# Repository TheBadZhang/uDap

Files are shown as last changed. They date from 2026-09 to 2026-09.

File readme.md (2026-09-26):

# uDap2

基于 **CH32X035F8U** 的 **CMSIS-DAP 调试器 + USB↔串口桥**，单颗 USB 全速设备口同时提供
SWD 调试和一路虚拟串口。仓库包含固件（`firmware/`）、KiCad 硬件设计（`hardware/`）与上位机
脚本（`software/`）。

- 调试器：CMSIS-DAP（bulk，WinUSB）——OpenOCD / pyOCD / probe-rs 可直接使用
- 桥接串口：CDC ACM，对端是目标板上的 USART4（PB0=TX / PB1=RX），**不限制波特率**
- SWD 时钟：请求 **≥6 MHz** 自动切到「快路径」，实测读写 **125 / 121 KiB/s**（16 KiB 块）
- SWD 推荐档位：**6 MHz**（更快与更快实际同速，填高只减时序余量）
- 串口环回：**2 Mbaud 持续满载零丢字节**（96~98 % 利用率）；分块发送时 6 Mbaud 也字节无误
- 桥接吞吐天花板：约 **200 KiB/s**（≈2 Mbaud），受 USB IN 侧调度限制，与 USB 带宽无关

---

## 1. 这是什么

一块 RISC-V MCU 做成的「调试器小板」：插上 USB 后主机看到**一个 CMSIS-DAP 探针**和
**一个串口**，两者共用同一颗芯片、同一根 USB 线。它替代的是「J-Link/DAPLink + 独立 USB-TTL」
两件套，用于嵌入式目标板的调试与串口日志。

数据通路：

```mermaid
flowchart LR
    PC["主机<br/>OpenOCD / pyOCD / 串口终端"]
    subgraph DAP["uDap2 (CH32X035F8U)"]
        USBFS["USB 全速设备"]
        DAPC["CMSIS-DAP<br/>DAP.c + sw_dp.c"]
        BR["CDC ↔ USART4 桥<br/>drv_uart.c"]
    end
    TGT["目标板<br/>SWCLK / SWDIO / nRESET"]
    UART["目标板 USART<br/>PB0=TX / PB1=RX"]

    PC -- "USB bulk (CMSIS-DAP)" --> USBFS
    PC -- "USB CDC ACM" --> USBFS
    USBFS --> DAPC
    USBFS --> BR
    DAPC -- "SWD 位翻转" --> TGT
    BR -- "USART4 115200~2M" --> UART
```

---

## 2. 硬件

### 主控芯片

| 项目 | 参数 |
| --- | --- |
| 型号 | **CH32X035F8U6**（沁恒 WCH，TSSOP-20） |
| 内核 | RISC-V，`rv32imacxw`（RV32IMAC + WCH 扩展，沁恒 QingKe V4 系列） |
| 主频 | 48 MHz，来自内部 HSI RC（无外部晶振），工程内 `CPU_CLOCK = 48000000` |
| Flash | 62 KiB 可用（链接脚本按「62K − 256B」划分，末尾 256B 留给 NV 配置） |
| SRAM | 20 KiB |
| USB | 内置 USB 全速（12 Mbps）设备控制器，DP/DM 固定在 PC16/PC17 |
| 固件体积 | Flash ≈ 26.2 KiB（`.bin` 26816 B）、RAM ≈ 19.1 KiB |

芯片外设在本工程中用到的部分：USBFS、USART4、GPIOA/GPIOB（含 BSHR/BCR 原子置位复位，
SWD 位翻转靠它做到单指令翻转）、SysTick、Flash。

### 板载与引脚分配

| 信号 | 引脚 | 说明 |
| --- | --- | --- |
| SWCLK | PA2 | SWD 时钟 |
| SWDIO | PA3 | SWD 双向数据（CFGLR 动态切输入/输出） |
| nRESET | PA5 | 低有效，复位目标 |
| 桥接串口 | PB0 = TX / PB1 = RX | USART4 |
| 状态灯 | PB12 | 高电平点亮，接 CMSIS-DAP `LED_CONNECTED_OUT` |
| USB | PC16 = DPDM / PC17 = DP | 固定复用 |

> ⚠️ 引脚取自参考工程，**尚未逐条对照 `hardware/uDap.kicad_sch` 核对**，上板前请确认。

USB 描述符（`src/dap/dap_main.c`）：

| 项目 | 值 |
| --- | --- |
| VID:PID | `0d28:0204`（与部分 DAPLink 相同，同插时需按序列号区分） |
| 制造商 / 产品 | `uDAP` / `uDAP CMSIS-DAP` |
| 序列号 | 默认 `DEADBEEF`（固定）；`--esig_sn=y` 时用芯片 ESIG 区的 96 位出厂 UID（24 位十六进制，每颗芯片唯一） |
| 复合接口 | 接口 0 = CMSIS-DAP 厂商自定义 bulk（MS OS 2.0 描述符自动装 WinUSB）<br/>接口 1/2 = CDC ACM |
| DAP 固件版本 | `0.1.0` |

---

## 3. 技术栈

### 固件

| 层 | 选型 | 说明 |
| --- | --- | --- |
| USB 协议栈 | **CherryUSB** | 上游 submodule，不改动；端口 glue 在 `src/port/` |
| 环形缓冲 | **CherryRB** | `chry_ringbuffer`，USB↔UART 两个方向的 FIFO |
| DAP 协议栈 | **CherryDAP** | CMSIS-DAP 命令解析、SWD 事务层 |
| 芯片 SDK | WCH CH32X035 SDK | Core / Peripheral / Startup / Linker，位于 `sdk/` |
| 语言 | C（gnu11），无 RTOS，裸机主循环 + 中断 | |
| USB 类 | CMSIS-DAP（WinUSB）+ CDC ACM | |
| 自定义 SWD 后端 | `src/dap/sw_dp.c` | 快/慢双路径位翻转，热路径放 RAM |

架构约定：`third_party/` **只放上游 submodule**，针对本板的适配（glue）全部放在
`src/port/`、`src/bsp/`、`src/dap/`、`src/drv/` 与 `src/usb_config.h`，升级依赖不会产生冲突。

### 工具链与构建

| 项目 | 选型 |
| --- | --- |
| 构建系统 | **xmake**（`firmware/xmake.lua`，工程根 = `firmware/`） |
| 编译器 | WCH RISC-V Embedded GCC 12（`riscv-wch-elf-*`，MounRiver Studio 2 自带） |
| 编译选项 | `-march=rv32imacxw -mabi=ilp32 -msmall-data-limit=8 -mno-save-restore`，`-O3 -Wall -std=gnu11`（release） |
| 优化 | LTO + `--gc-sections`；`.highcode` 段启动时从 Flash 搬到 RAM 执行 |
| 辅助脚本 | `firmware/build.ps1`（PowerShell，包了工具链路径与 `--dap=y/n` / `--esig_sn=y/n`） |
| 烧录 | `wlink`（WCH 官方）或 `wchisp` |

### 上位机 / 测试脚本

Python（pyserial）+ TCL（OpenOCD）+ PowerShell，全部在 `firmware/tools/`。

### 硬件设计

KiCad 工程：`hardware/uDap.kicad_sch` / `uDap.kicad_pcb`（含 Type-C 子图 `usb_typec.kicad_sch`）。

---

## 4. 功能特性

- **CMSIS-DAP**：SWD 传输，支持 `DAP_Transfer` / `DAP_TransferBlock` / `DAP_ExecuteCommands`；
  nRESET 可控；已实测 OpenOCD 能读写 STM32F411 的 Flash 与 RAM。
- **快/慢双路径 SWD**：请求时钟 < 6 MHz 走慢路径（带可调延时，兼容长线/慢目标）；
  ≥ 6 MHz 走快路径（固定指令数时序，约 6 MHz 实际 SWCLK）。阈值由 CherryDAP 的
  `MAX_SWJ_CLOCK(DELAY_FAST_CYCLES) = (48M/2)/(2+DELAY_FAST_CYCLES)` 决定，
  本工程在 `DAP_config.h` 里把 `DELAY_FAST_CYCLES` 设为 2 → 阈值 **6 MHz**
  （上游默认 0，即 12 MHz）。
- **USB↔串口桥**：CDC ACM 与 USART4 双向搬运，波特率由主机 `SET_LINE_CODING` 实时设定。
- **不限制波特率**：主机下什么速率就设什么（不拒绝、不截断）。USART 是 16 倍过采样，
  `BRR = 48 MHz / 波特率`，标称上限 3 Mbaud；实测 6 Mbaud（BRR=8，USARTDIV<1）也能字节无误。
  详见第 6.4 节。
- **CDC 侧背压**：UART TX FIFO 余量不足时不重挂 OUT 端点，主机 bulk 写被 NAK 挡住，
  主机侧自然阻塞在串口波特率上，**不丢字节**（见第 6.2 节）。
- **状态指示灯**：PB12 显示主机是否已连接（由 `DAP_HostStatus` 驱动）。
- **可选唯一序列号**：`--esig_sn=y` 时用芯片 ESIG 区的 96 位出厂 UID 作 USB 序列号
  （同一份字符串也用于 CMSIS-DAP 的 `DAP_GetSerNum`），多块板子可区分；
  默认仍是固定的 `DEADBEEF`。见 `firmware/README.md` 的「序列号」一节。
- **可裁剪**：`xmake f --dap=n` 可关掉调试器功能，只编 USB 骨架（Flash 12.5 KiB）。

---

## 5. 快速开始

### 构建

```powershell
cd firmware

# 便捷脚本（release，CMSIS-DAP 默认启用）
.\build.ps1
.\build.ps1 -Dap n        # 只编 USB 骨架
.\build.ps1 -EsigSn y     # 用芯片 ESIG UID 作序列号（每颗芯片唯一）
.\build.ps1 -Clean        # 先清理

# 或直接用 xmake
$env:WCH_TOOLCHAIN_ROOT = "D:/program/wch/MounRiver_Studio2/resources/app/resources/win32/components/WCH/Toolchain/RISC-V Embedded GCC12"
xmake f -m release -y
xmake -r

# 用芯片 ESIG UID 作序列号（每颗芯片唯一，多块板子可区分）
xmake f -m release --dap=y --esig_sn=y -y
xmake -r
```

产物：`firmware/build/release/firmware.elf` / `.bin` / `.map`。

> ⚠️ xmake 会把 option 值持久化到本地配置，构建脚本每次显式传 `--dap=...` 与
> `--esig_sn=...`；直接敲 xmake 时也请显式指定，否则结果会被上一次的配置决定。
>
> ⚠️ `--esig_sn=y` **需要** `--dap=y`（序列号在 `src/dap/dap_main.c` 里设置，
> 该文件只在启用 CMSIS-DAP 时编译）。这个组合会被直接拒绝并给出提示。
> 打开后 USB 序列号从 `DEADBEEF` 变成芯片 UID，主机侧会当成**另一台设备**，
> 需要重新匹配一次驱动（WinUSB 自动匹配，无需手工装）。

### 烧录

```powershell
wlink flash firmware/build/release/firmware.elf
```

### 使用

```sh
# 调试器（会同时看到 uDAP CMSIS-DAP 探针和一个 CDC 串口）
openocd -f interface/cmsis-dap.cfg -f target/stm32f4x.cfg
probe-rs info --chip stm32f411ceu --probe DEADBEEF

# 串口
python -m serial.tools.miniterm COM21 115200
```

> 上面的 `--probe DEADBEEF` 是**默认**序列号。若用 `--esig_sn=y` 构建过，
> 探针标识会变成芯片 UID（24 位十六进制），用 `probe-rs list` 或
> `Get-PnpDevice` 查实际值。

---

## 6. 性能实测

### 6.1 SWD 调试吞吐（频率扫描）

**方法**：`firmware/tools/openocd_speed_test.tcl`（测试块先备份、测完恢复，不破坏目标程序）。

```powershell
# 在仓库根目录执行

# 单点
.\firmware\tools\speed.ps1 -Khz 6000 -Bytes 65536 -Rounds 3

# 整条频率扫描（本次数据即由此产生）
.\firmware\tools\openocd_speed_sweep.ps1 -Rounds 5 -Warmup 1
```

> 两个脚本都带 `-FastMinKhz`（默认 6000），**只用于打印「快/慢路径」标注**，
> 不影响实际速度。它必须与固件 `DAP_config.h` 里的 `DELAY_FAST_CYCLES` 保持一致：
> 阈值 = `24 MHz / (2 + DELAY_FAST_CYCLES)`。改固件阈值时记得同步这个默认值。

**环境**

| 项目 | 值 |
| --- | --- |
| 探针 | 本板 uDAP（`0d28:0204`，序列号 `DEADBEEF`，DAP 固件 `0.1.0`） |
| 目标 | STM32F411CEU6，IDCODE `0x2BA01477` |
| 测试区 | 目标 RAM `0x20000000`（主表 16 KiB；「块大小的影响」另用 64/128 KiB） |
| 主机工具 | OpenOCD 0.11.0+dev-snapshot（MounRiver Studio 2 内置） |
| 统计方式 | 每频率预热 1 轮后连测 5 轮取平均（预热不计入） |

| SWCLK 请求 | 写 (KiB/s) | 读 (KiB/s) | 路径 |
| ---: | ---: | ---: | :--- |
| 100 kHz | 4.6 | 4.7 | 慢 |
| 200 kHz | 8.3 | 8.6 | 慢 |
| 300 kHz | 11.8 | 12.0 | 慢 |
| 400 kHz | 15.0 | 14.8 | 慢 |
| 500 kHz | 18.7 | 18.7 | 慢 |
| 600 kHz | 21.4 | 21.6 | 慢 |
| 800 kHz | 25.2 | 24.0 | 慢 |
| 1000 kHz | 31.7 | 31.4 | 慢 |
| 1500 kHz | 40.8 | 40.3 | 慢 |
| 2000 kHz | 41.2 | 40.3 | 慢 |
| 2500 kHz | 54.3 | 45.8 | 慢（开始饱和） |
| 3000 kHz | 53.8 | 42.8 | 慢（饱和） |
| 4000 kHz | 54.2 | 45.3 | 慢（饱和） |
| 5000 kHz | 53.3 | 45.1 | 慢（饱和） |
| 5750 kHz | 54.1 | 45.5 | 慢（饱和，最后一档） |
| **6000 kHz** | **125.4** | **121.0** | **快（拐点）** |
| 8000 kHz | 126.7 | 121.8 | 快 |
| 10000 kHz | 115.9 | 113.9 | 快 |
| 12000 kHz | 126.3 | 119.0 | 快 |

> 慢路径数值有 ±5 % 波动（同一档重测会在 53 ~ 56 KiB/s 之间浮动），
> 快路径 ±10 %。**不要拿单次测量去比较两版固件。**

曲线（写，KiB/s）：

```
  100 kHz ▏█                                          4.6  ┐
  200 kHz ▏█▊                                         8.3  │
  500 kHz ▏████▏                                     18.7  ├ 慢路径线性区
 1000 kHz ▏██████▊                                  31.7  │  （速度 ∝ 频率）
 1500 kHz ▏█████████                                40.8  ┘
 2000 kHz ▏█████████                                41.2  ┐ 慢路径饱和
 4000 kHz ▏████████████                             54.2  │  （延时被钳到最小值，
 5750 kHz ▏████████████                             54.1  ┘    再提频率无用）
 6000 kHz ▏████████████████████████████▏           125.4    快路径（2.3×）
```

**块大小的影响**（同环境，取每次都能稳定拿到的值）

| 测试块 | 6 MHz 写 | 6 MHz 读 | 5.75 MHz 写（慢） | 5.75 MHz 读（慢） |
| ---: | ---: | ---: | ---: | ---: |
| 16 KiB | **125.4** | **121.0** | 54.1 | 45.5 |
| 64 KiB | 109.5 | 108.0 | — | — |
| 128 KiB | 94.7 | 91.6 | 51.2 | 43.9 |

**块越小越快**（16 KiB 最优），因为每轮都要等一次 USB 往返 + OpenOCD 的命令封装；
块大到一定程度后，往返开销占比下降的收益被别的因素抵消。**测速请固定块大小**。

**结论**

1. **慢路径在约 2.5 MHz 就已经饱和**（≈54 写 / 45 读 KiB/s）。2.5 MHz 到 5.75 MHz 之间
   请求更高的时钟完全没有收益 —— 延时参数已被钳到最小值，实际 SWCLK 不再上升。
2. **6 MHz 是拐点**：跨过阈值切到快路径，写速度 54 → 125 KiB/s（**2.3 倍**），读 45 → 121。
3. **6 MHz 与 12 MHz 的实际速度一样**（快路径的实际 SWCLK 由固定指令数决定，约 6 MHz）。
   每次都能拿到的值在写 104 ~ 127 / 读 102 ~ 122 KiB/s 之间浮动。
   **填 6 MHz 即可**，不必填更高：请求值只影响相对目标的时序余量，不影响速度。
4. **稳定性已强化验证**：6 MHz、128 KiB 块、10 轮全部通过（94.7 / 91.6 KiB/s），
   无 ACK 错误或缺字节。
5. 读速度低于写速度（约 −10 %），因为读操作需要在 SWDIO 上采样并打包，时序更长。
6. 这个数字是「SWD 链路吞吐」，与目标 Flash 编程速度不是一回事 —— 烧 Flash 还要叠加
   目标自身的 Flash 控制器耗时。

### 6.2 COM 口环回吞吐与利用率

**方法**：`firmware/tools/com_loopback_speed.py`。
需要把 DAP 的 **PB0(TX) 与 PB1(RX) 短接**，主机写进 COM 口的字节经
USB→DAP→UART→环回→UART→DAP→USB 回到主机。脚本用两个线程**同时**发与收
（固件 TX FIFO 只有 1 KiB，边写边读才不会撑爆、也不会在被背压挡住时空等），
载荷按波特率自动缩放，收满后**逐字节比对**。

```powershell
python .\firmware\tools\com_loopback_speed.py --seconds 2 --repeats 3
python .\firmware\tools\com_loopback_speed.py --baud 115200,2000000
```

**环境**：COM21（本板 uDAP 的 CDC 口），并已用跳线把 PB0(TX) 与 PB1(RX) 短接。

**两个「利用率」的含义**

- **UART 利用率** = 实测字节率 ÷ (波特率 / 10)。8N1 每字节占 10 个位时间，
  所以 `波特率 / 10` 是串口线的理论上限。这一列回答「串口线有没有被榨干」。
- **USB 利用率** = 双向字节率（收 + 发）÷ 1.216 MB/s。全速 USB 每 1 ms 帧最多
  19 × 64 字节批量载荷，即 1 216 000 B/s。这一列回答「USB 侧还有多少余量」。

**结果**（每档 2 s 目标载荷、3 次取中位）

| 波特率 | 载荷 | 用时 | 实测速度 | UART 线速率 | **UART 利用率** | USB 利用率 |
| ---: | ---: | ---: | ---: | ---: | ---: | ---: |
| 9 600 | 4 KiB | 4.259 s | 961.6 B/s（0.94 KiB/s） | 960 B/s | **100.2 %** | 0.2 % |
| 19 200 | 4 KiB | 2.130 s | 1 923.0 B/s（1.88 KiB/s） | 1 920 B/s | **100.2 %** | 0.3 % |
| 38 400 | 8 KiB | 2.130 s | 3 845.7 B/s（3.76 KiB/s） | 3 840 B/s | **100.2 %** | 0.6 % |
| 57 600 | 12 KiB | 2.129 s | 5 771.0 B/s（5.64 KiB/s） | 5 760 B/s | **100.2 %** | 1.0 % |
| 115 200 | 24 KiB | 2.132 s | 11 526.3 B/s（11.26 KiB/s） | 11 520 B/s | **100.1 %** | 1.9 % |
| 230 400 | 48 KiB | 2.127 s | 23 103.9 B/s（22.56 KiB/s） | 23 040 B/s | **100.3 %** | 3.8 % |
| 460 800 | 92 KiB | 2.038 s | 46 217.3 B/s（45.13 KiB/s） | 46 080 B/s | **100.3 %** | 7.6 % |
| 921 600 | 180 KiB | 1.994 s | 92 427.2 B/s（90.26 KiB/s） | 92 160 B/s | **100.3 %** | 15.2 % |
| 1 000 000 | 196 KiB | 2.004 s | 100 131.1 B/s（97.79 KiB/s） | 100 000 B/s | **100.1 %** | 16.5 % |
| 1 500 000 | 296 KiB | 2.018 s | 150 188.1 B/s（146.67 KiB/s） | 150 000 B/s | **100.1 %** | 24.7 % |
| **2 000 000** | 392 KiB | 2.004 s | 200 277.0 B/s（195.58 KiB/s） | 200 000 B/s | **100.1 %** | 32.9 % |

> 利用率会略高于 100 %（100.1 ~ 100.3 %）。这是因为 CH32X035 的 48 MHz 来自**内部 HSI RC**，
> 实际频率与标称值有零点几百分点的偏差 —— 也就是串口线比标称波特率快了同样的比例。
> 数值 ≥100 % 就说明 UART 侧已被完全榨干，瓶颈不在 DAP 固件。
>
> ⚠️ 本表是「成功跑完的那些轮」的平均值（每档 3 轮取中位），**不代表都能成功**：
> 从 1.9 Mbaud 起会偶发丢字节，2 Mbaud 的成功率约 4 / 10。可靠性问题见 6.3 节。

**结论**

1. **从 9 600 到 2 000 000 baud，UART 利用率始终 ≈100 %** —— 桥接固件在整条波特率
   区间内都不是瓶颈，串口线速就是端到端速度。
2. **USB 侧余量很大**：即使 2 Mbaud，USB 利用率也只有 33 %。
   瓶颈完全在 UART 侧，**不是 USB 带宽**。
3. 但**继续提高波特率不会再加速**：实测桥接的吞吐天花板是 **≈190~200 KiB/s**，
   正好落在 2 Mbaud。限制来自 USB IN 侧：`chry_dap_cdc_bridge()` 每次主循环迭代
   只发起**一次** CDC IN 传输（最多 512 B），且必须等它完成后才能发下一次。
   详见 6.4 节。

### 6.3 持续满载的可靠性边界

上一节的表格是把整块载荷**一次性写出去**（sustained）测的。这种方式下 DAP 的收发是
**持续并发**的，中断负载最高，波特率过高时会**偶发丢字节**（丢的是连续一小段，
典型 50 ~ 170 字节，特征是 DAP 的 RX FIFO 溢出 —— RX 侧没有背压手段）。

每档 2 s 级载荷（约 370~400 KB）、重复 10 次：

| 波特率 | 通过率 | 实测速度 | 结论 |
| ---: | :---: | ---: | :--- |
| 1 800 000 | **10 / 10** | 178 052 B/s（173.9 KiB/s） | 可靠（另有 3 次 1.44 MB 超长测试也全通过） |
| 1 850 000 | 9 / 10 | 184 849 B/s（180.5 KiB/s） | 边缘 |
| 1 900 000 | 6 / 10 | 192 264 B/s（187.8 KiB/s） | 不可靠 |
| 2 000 000 | 4 / 10 | 200 277 B/s（195.6 KiB/s） | 不可靠 |

2 Mbaud 下的丢字节与**持续时长**正相关（同一波特率，缩短载荷即可全通过）：

| 载荷 | 持续时长 | 通过率 |
| ---: | ---: | :---: |
| 8 KiB | 0.04 s | **20 / 20** |
| 64 KiB | 0.33 s | **10 / 10** |
| 128 KiB | 0.65 s | 7 / 8 |
| 256 KiB | 1.3 s | 6 / 8 |
| 512 KiB | 2.6 s | 4 / 6 |

但把发送方式换成**分块 + 等回包**（`com_loopback_paced.py`）后，同一个 2 Mbaud
不仅全通过，速率还更高：

| 发送方式 | 波特率 | 块大小 | 总量 | 结果 | 等效速率 | 利用率 |
| --- | ---: | ---: | ---: | :---: | ---: | ---: |
| 一次性写（sustained） | 2 000 000 | 全部 | 400 KB | 4 / 10 | 195.6 KiB/s | 100.1 % |
| **分块 + 等回包** | 2 000 000 | 4 096 B | 256 KiB | **3 / 3** | **188.7 KiB/s** | **96.6 %** |
| **分块 + 等回包** | 2 000 000 | 4 096 B | 32 KiB | **2 / 2** | **191.3 KiB/s** | **97.9 %** |

**所以：**

- **要长时间零丢字节，首选「分块 + 等回包」的发送方式，并把波特率设在 2 Mbaud**：
  实测 256 KiB 连跑 3 次全部逐字节正确，利用率 96.6 %。
- 如果用**一次性大块写**（持续满载、不自流控），则把波特率降到 **1.8 Mbaud 以内**。
- **根因**是中断 / 排水负载（RX 与 TX 持续并发），不是 FIFO 大小 ——
  把 RX FIFO 从 1 KiB 加到 2 KiB 曾被实测验证过**无改善**（失败形态是「停顿」而非渐进溢出）。

### 6.4 撤除波特率上限之后：高波特率实测

早期固件在 `SET_LINE_CODING` 里对 `> 2 Mbaud` 的请求直接 STALL。现已**撤除该限制**
（见 `dap_main.c` 里「关于 COM 口波特率」的说明），主机下什么速率就设什么。
本节回答两个问题：① UART 到底能产生多高的速率；② 更高的速率有没有用。

#### UART 实际能产生的速率

CH32X035 的 USART 是 **16 倍过采样**，`BRR = fPCLK / 波特率` 必须是整数，
所以实际速率只能落在 `48 MHz / BRR` 这些离散值上（脚本复刻了 SDK `USART_Init()`
的 BRR 算法来推算）：

| 请求波特率 | BRR | UART 实际速率 | 偏差 | 备注 |
| ---: | ---: | ---: | ---: | --- |
| 115 200 | 417 | 115 108 | −0.08 % | |
| 921 600 | 52 | 923 077 | +0.16 % | |
| 1 500 000 | 32 | 1 500 000 | 0.00 % | |
| **2 000 000** | **24** | **2 000 000** | **0.00 %** | 精确，推荐 |
| 2 500 000 | 19 | 2 526 316 | **+1.05 %** | 偏差偏大 |
| 3 000 000 | 16 | 3 000 000 | 0.00 % | USARTDIV = 1，16 倍过采样的**标称上限** |
| 3 500 000 | 14 | 3 428 571 | −2.04 % | BRR < 16，超出规范 |
| 4 000 000 | 12 | 4 000 000 | 0.00 % | BRR < 16，超出规范 |
| 6 000 000 | 8 | 6 000 000 | 0.00 % | BRR < 16，超出规范 |
| 12 000 000 | 4 | 12 000 000 | 0.00 % | BRR < 16，超出规范 |

**BRR < 16 超出规范，但实测仍然能用**（见下面的矩阵）。不过既然速率再高也换不来
吞吐（见本节末），没必要用到那里。

#### 波特率 × 发送块大小矩阵

`com_loopback_matrix.py`：每格发送 32 KiB（192 B / 512 B / 4 096 B 三种块大小），
块间无额外空隙（靠 USB 往返天然拉开），逐字节校验，重复 2 次。
格子 = 通过次数（2/2 = 全通过）：

| 波特率 | 192 B 块 | 512 B 块 | 4 096 B 块 |
| ---: | :---: | :---: | :---: |
| 2 000 000 | 2/2 | 2/2 | **2/2** |
| 2 500 000 | 2/2 | 0/2 | 1/2 |
| 3 000 000 | 2/2 | 0/2 | 0/2 |
| 4 000 000 | 2/2 | 0/2 | 0/2 |
| 6 000 000 | 2/2 | 0/2 | 0/2 |

对应的**等效速率**（KiB/s，括号内为 UART 利用率）：

| 波特率 | 192 B 块 | 512 B 块 | 4 096 B 块 |
| ---: | ---: | ---: | ---: |
| 2 000 000 | 144.0（74.4 %） | 170.5（87.3 %） | **191.3（97.9 %）** |
| 2 500 000 | 140.0（57.4 %） | — | 198.8（81.5 %，仅 1/2） |
| 3 000 000 | 162.8（55.6 %） | — | — |
| 4 000 000 | 163.7（41.9 %） | — | — |
| 6 000 000 | 164.5（28.1 %） | — | — |

更细的块大小扫描（每格 16 KiB、重复 3 次）显示可靠性的**临界粒度在 192 ~ 256 B**
之间，且与波特率基本无关：

| 波特率 | 64 B | 128 B | 192 B | 256 B | 384 B | 512 B |
| ---: | :---: | :---: | :---: | :---: | :---: | :---: |
| 2 500 000 | 3/3 | 3/3 | 2/3 | 1/3 | 2/3 | 1/3 |
| 3 000 000 | 3/3 | 3/3 | 3/3 | 1/3 | 0/3 | 0/3 |
| 4 000 000 | 3/3 | 3/3 | 3/3 | 3/3 | 0/3 | 0/3 |
| 6 000 000 | 3/3 | 3/3 | 3/3 | 1/3 | 0/3 | 0/3 |

#### 关键实验：固定平均速率，只改块大小

「块大了就丢」到底是**瞬间突发太猛**，还是**平均速率太高**？在 2.5 Mbaud 下把
平均速率都固定在约 108 KB/s，只改块大小与间隔：

| 块大小 | 块间空隙 | 平均速率 | 结果 |
| ---: | ---: | ---: | :---: |
| 192 B | 1 ms | ≈108 KB/s | 1 / 2 |
| 384 B | 2 ms | ≈108 KB/s | 0 / 2 |
| 768 B | 4 ms | ≈108 KB/s | 0 / 2 |
| 1 536 B | 8 ms | ≈108 KB/s | 0 / 2 |

**结论：决定成败的是块（突发）大小，不是平均速率** —— 加长空隙并不能补偿更大的块。
换句话说，DAP 的 UART→USB 排水侧来不及把一整块搬走，RX FIFO 在块内就溢出了；
块间的空隙再长也与「块内那一段」无关。

#### 结论：高波特率换不来吞吐

1. **桥接的吞吐天花板是 ≈190 ~ 200 KiB/s**，2 Mbaud 恰好就在这个位置（利用率 98 %）。
   再往上提波特率，**一个字节都多不出来**。
2. 若强制用高波特率，则必须把发送块压到 **≤ 192 B** 才能逐字节无误；
   代价是每块都要等一次 USB 往返，等效速率反而**降到约 165 KiB/s**，
   而且波特率越高利用率越低（6 Mbaud 只有 28 %）。
3. 所以**推荐的档位就是 2 Mbaud**：速率精确（偏差 0.00 %）、正好触到天花板、
   配合分块发送可长时间零丢字节。
4. 限制来自 **USB IN 侧的传输调度**：`chry_dap_cdc_bridge()` 每次主循环只发起一次
   IN 传输且要等它完成，不是 USB 带宽不够 —— 2 Mbaud 时双向合计仅占全速 USB
   批量上限的 33 %。

---

## 7. 已知限制

| 限制 | 说明 |
| --- | --- |
| 吞吐天花板 ≈190~200 KiB/s | 桥接的极限是 USB IN 侧调度，与波特率无关（见 6.4）。**把波特率提到 2 Mbaud 以上不会更快**，反而必须缩小发送块才能不丢字节，等效速率更低。 |
| 高波特率需配分块发送 | ≥2.5 Mbaud 时只有发送块 ≤192 B 才逐字节无误（见 6.4）。持续满载收发（≥1.9 Mbaud）会偶发丢字节 —— RX 方向**没有背压手段**（UART 侧无 RTS/CTS），是并发时真正脆弱的一侧。 |
| 超规范速率 | `BRR < 16`（>3 Mbaud）超出 16 倍过采样规范，实测能用但无收益；且 2.5 Mbaud 等档位的实际速率与请求值偏差可达 1~2 %，接真实目标板时需自行留出容差。 |
| 快路径实际时钟固定 | 快路径的 SWCLK 由指令数决定（约 6 MHz），与请求的 6 ~ 24 MHz 无关；请求越高只是余量越薄。**所以推荐的请求值就是 6 MHz** —— 正好是拐点，余量最厚。 |
| 单颗状态灯 | PB12 接的是 CMSIS-DAP `LED_CONNECTED_OUT`，由主机的 `DAP_HostStatus` 驱动。**OpenOCD 不发该命令 → 灯不亮**；pyOCD 会亮。详见 `firmware/README.md`。 |
| 引脚未核对原理图 | SWD/nRESET/串口引脚取自参考工程，需按 `hardware/uDap.kicad_sch` 复核。 |
| HSI 无晶振 | 波特率/时序精度依赖内部 RC，与标称值有零点几百分比偏差。 |

---

## 8. 目录结构

```
uDap2/
├── readme.md                    本文件：项目总览 + 性能数据
├── firmware/                    固件工程（xmake 工程根）
│   ├── src/                     本工程代码（应用 + 移植 glue）
│   │   ├── main.c               入口（ENABLE_DAP 分两条路径）
│   │   ├── system_ch32x035.c    时钟与系统初始化
│   │   ├── ch32x035_it.c        中断实现
│   │   ├── usb_config.h         CherryUSB 应用侧配置（必选）
│   │   ├── bsp/                 延时 / 打印 / 系统 / USB 硬件初始化
│   │   ├── port/                CherryUSB 的 CH32X035 USBFS 端口 glue
│   │   ├── dap/                 CMSIS-DAP glue（DAP_config.h / dap_main.c / sw_dp.c）
│   │   └── drv/drv_uart.c       CDC ↔ USART4 桥（CherryRB FIFO + 背压）
│   ├── sdk/                     WCH CH32X035 SDK
│   ├── third_party/             仅上游 submodule（cherryusb / cherryrb / cherrydap）
│   ├── docs/                    性能文档与原始 CSV
│   │   ├── performance_stm32f411.md    SWD 基线文档（含 6 MHz 阈值变更记录）
│   │   ├── swd_sweep_fast6m.csv        本文 6.1 节的原始数据（6 MHz 阈值版）
│   │   ├── swd_sweep_16k.csv           同一扫描的旧数据（12 MHz 阈值版，留作对照）
│   │   ├── com_loopback.csv            本文 6.2 节的原始数据
│   │   └── com_loopback_highbaud.csv   本文 6.4 节的原始数据
│   ├── tools/                   测速 / 串口测试脚本
│   ├── xmake.lua                构建脚本
│   └── README.md                固件内部细节（引脚、构建陷阱、与参考工程差异）
├── hardware/                    KiCad 工程（uDap.kicad_sch / uDap.kicad_pcb）
└── software/                    上位机
```

---

## 9. 测试脚本一览

| 脚本 | 用途 |
| --- | --- |
| `firmware/tools/openocd_speed_test.tcl` | 单频率 SWD 内存读写测速（会被 `speed.ps1` / 扫描脚本调用） |
| `firmware/tools/speed.ps1` | 单个 SWCLK 频率的 SWD 测速 |
| `firmware/tools/openocd_speed_sweep.ps1` | **频率扫描**，一次跑一串频率并汇总成表（本文 6.1 节） |
| `firmware/tools/com_loopback_speed.py` | **COM 口环回吞吐 / 利用率**测试，持续满载模式（本文 6.2、6.3 节） |
| `firmware/tools/com_loopback_paced.py` | **分块 / 间隔发送**测试，含 BRR 与实际波特率推算（本文 6.3、6.4 节） |
| `firmware/tools/com_loopback_matrix.py` | **波特率 × 块大小矩阵**扫描，找最小可靠发送粒度（本文 6.4 节） |
| `firmware/tools/uart_*.py` | USART4 桥的连通性 / 全双工 / 流控 / 压力测试 |
| `firmware/tools/dap_probe_check.py` | 探针基本信息检查 |

复现本文数据：

```powershell
# 6.1 SWD 频率扫描（需接好目标板）
.\firmware\tools\openocd_speed_sweep.ps1 -Rounds 5 -Warmup 1

# 6.2 / 6.3 COM 环回，持续满载（需 PB0-PB1 短接）
python .\firmware\tools\com_loopback_speed.py --seconds 2 --repeats 3

# 6.3 / 6.4 分块发送（可用 --chunk / --gap-ms 控制发送粒度）
python .\firmware\tools\com_loopback_paced.py --baud 2000000 --chunk 4096 --total 262144 --repeats 3
python .\firmware\tools\com_loopback_paced.py --baud 6000000 --chunk 192 --total 32768

# 6.4 波特率 × 块大小矩阵
python .\firmware\tools\com_loopback_matrix.py `
    --baud 2000000,2500000,3000000,4000000,6000000 --chunk 192,512,4096 `
    --total 32768 --repeats 2 --csv firmware\docs\com_loopback_highbaud.csv
```

---

## 10. 第三方依赖

```sh
git submodule update --init
```

| submodule | commit | 版本 |
| --- | --- | --- |
| `firmware/third_party/cherryusb` | `0e40349` | v1.6.1-82 |
| `firmware/third_party/cherryrb` | `19ea7c6` | v1.0.0 |
| `firmware/third_party/cherrydap` | `c40bb5a` | HSLinkPro-2.4.2-41 |

均在各自的开源许可下使用；本工程对子模块**不做修改**，所有适配放在 `firmware/src/`。

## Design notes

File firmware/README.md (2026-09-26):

# CH32X035F8U DAP（uDap2 固件）

CH32X035F8U 上的 CMSIS-DAP 调试器固件，xmake + WCH RISC-V GCC 构建。

## 目录结构

本仓库根目录为 `uDap2/`，固件工程根是 **`firmware/`**（`xmake.lua` 所在层级）。

```
uDap2/
├── firmware/               ← 固件工程根（xmake 工程）
│   ├── src/                本工程代码（应用 + 移植 glue）
│   │   ├── main.c          应用入口（用 ENABLE_DAP 区分 DAP / 仅 USB 两条路径）
│   │   ├── system_ch32x035.c  时钟与系统初始化
│   │   ├── ch32x035_it.c   中断实现
│   │   ├── ch32x035_conf.h SDK 配置
│   │   ├── usb_config.h    CherryUSB 应用侧配置（必选）
│   │   ├── bsp/
│   │   │   ├── bsp_usb.c       CH32X035 USBFS 硬件初始化（必选）
│   │   │   ├── bsp_delay.c     SysTick 延时/时间 + Delay_Init/Us/Ms 兼容层
│   │   │   ├── bsp_print.c     newlib retarget（_write / _sbrk）
│   │   │   └── bsp_system.c    进 ISP 复位
│   │   ├── port/
│   │   │   └── usb_ch32x035_dc_usbfs.c   CherryUSB 的 CH32X035 USBFS 设备端口 glue（必选）
│   │   ├── dap/            CMSIS-DAP glue（可选）
│   │   │   ├── DAP_config.h    SWD / nRESET 引脚与时序配置
│   │   │   ├── dap_main.c      USB 描述符、WinUSB/MSOS、DAP 与 CDC 端点分发
│   │   │   └── sw_dp.c         SWD 位翻转实现（CherryDAP 的传输后端）
│   │   └── drv/
│   │       └── drv_uart.c      CDC <-> USART4 桥（CherryRB FIFO）
│   ├── sdk/                WCH CH32X035 SDK（Core / Peripheral / Debug / Startup / Ld / EXAM）
│   ├── third_party/        仅上游依赖，全部为 submodule
│   │   ├── cherryusb       https://github.com/cherry-embedded/CherryUSB.git
│   │   ├── cherryrb        https://github.com/cherry-embedded/CherryRB.git
│   │   └── cherrydap       https://github.com/cherry-embedded/CherryDAP.git
│   ├── toolchains/wch-riscv/  工具链探测（WCH_TOOLCHAIN_ROOT 或 MounRiver 默认路径）
│   ├── docs/               性能文档
│   ├── tools/              测速 / 串口测试脚本
│   ├── xmake.lua           构建脚本
│   └── build.ps1           便捷构建脚本
├── hardware/               KiCad 工程（uDap.kicad_sch / uDap.kicad_pcb）
└── software/               上位机等
```

`firmware/third_party/` 只放上游 submodule（**不改动 submodule 内容**）；针对本工程的
移植层（glue）放在 `firmware/src/port/`、`src/bsp/`、`src/dap/`、`src/drv/` 与
`src/usb_config.h`。

submodule 的 git 管理数据在 `.git/modules/firmware/third_party/`，与工作区路径一一对应；
若以后再次整体移动工程目录，记得同步修正各 submodule 的 `.git` 文件与
`.git/modules/.../config` 里的 `core.worktree`。

## USB（必选）

本芯片必然使用 USB，所以以下三部分在 `xmake.lua` 中**无条件编译**，缺文件直接报错
（`USB is mandatory: missing ...`），不会默默编出一个没有 USB 的固件：

| 部分 | 位置 |
| --- | --- |
| CherryUSB 初始化配置 | `src/usb_config.h` |
| CherryUSB 核心 + CDC ACM 类 | `third_party/cherryusb/`（submodule） |
| CH32X035 USBFS 设备端口 glue | `src/port/usb_ch32x035_dc_usbfs.c` |
| CH32X035 USB 硬件初始化 | `src/bsp/bsp_usb.c` |

注意：CherryUSB 的端口层把 `usb_dc_low_level_init()` / `usb_dc_low_level_deinit()` 声明为
`__WEAK` 空实现，**USB 时钟、PC16/PC17、AFIO PHY、NVIC 必须由应用侧提供**，否则
`usbd_initialize()` 之后 USB 既不枚举也不进中断。`src/bsp/bsp_usb.c` 覆盖了这两个弱函数，
并按 WCH 官方例程区分供电电压：

- 5V 供电：关闭 `PHY_V33`，UDP 内部上拉 10K；
- 3.3V 供电：使能 `PHY_V33`，UDP 内部上拉 1.5K（USB 2.0 全速规范要求）。

调用链是 `usbd_initialize()` → `usb_dc_init()` → `usb_dc_low_level_init()`，因此应用侧必须先
调用 `NVIC_PriorityGroupConfig()` 设定优先级分组。

## CMSIS-DAP（可选）

调试器功能（CherryDAP + `src/dap`、`src/drv` glue）是可选的，默认启用，可以关闭：

```powershell
.\build.ps1 -Dap n      # 便捷脚本：关闭
.\build.ps1             # 便捷脚本：启用（-Dap y 是默认值）

xmake f --dap=n -y      # 直接用 xmake：关闭
xmake f --dap=y -y      # 直接用 xmake：启用
```

> ⚠️ **xmake 会把选项值持久化**到本地配置：执行过 `xmake f --dap=n` 之后，再运行
> 不带 `--dap` 的 `xmake f` 仍然保持关闭（实测：关闭后只跑 `xmake f -m release -y`
> 再构建，产物仍是 12.47 KiB）。因此 `build.ps1` 每次都显式传 `--dap=...`，
> 保证构建结果只由参数决定；直接敲 xmake 时也请显式指明。

`xmake.lua` 里的 `option("dap")` 控制它，并传递 `-DENABLE_DAP=0/1` 给 C 代码；
`src/main.c` 用该宏区分两条初始化路径（关闭时不再调 `chry_dap_init()`）。
两个实测尺寸：

| 配置 | Flash | RAM |
| --- | --- | --- |
| `--dap=y`（默认，`--esig_sn=n`） | 26.09 KiB | 19.16 KiB |
| `--dap=y --esig_sn=y` | 26.71 KiB | 19.16 KiB |
| `--dap=n` | 12.47 KiB | 11.60 KiB |

启用 DAP 时会校验 `src/dap/DAP_config.h`、`dap_main.c`、`sw_dp.c`、`src/drv/drv_uart.c`
是否存在，缺文件直接报错并提醒可用 `--dap=n` 关闭。

### 序列号：固定值 / 芯片 ESIG UID

默认所有板子的 USB 序列号都是固定的 `DEADBEEF` —— 多块板子同时插在一台机器上时
无法区分（VID:PID 也相同）。`option("esig_sn")` 打开后改用芯片 ESIG 区的
**96 位出厂 UID**（出厂烧录、只读、每颗芯片唯一），转成 24 个大写十六进制字符：

```powershell
.\build.ps1 -EsigSn y     # 便捷脚本：用芯片 UID
.\build.ps1               # 默认：固定 DEADBEEF（-EsigSn n）

xmake f --dap=y --esig_sn=y -y
```

**寄存器定义**（代码在 `src/dap/dap_main.c`，见 CH32X035 应用手册第 19 章
「电子签名（ESIG）」）：

| 地址 | 名称 | 内容 |
| --- | --- | --- |
| `0x1FFFF7E8` | `R32_ESIG_UNIID1` | `U_ID[31:0]` |
| `0x1FFFF7EC` | `R32_ESIG_UNIID2` | `U_ID[63:32]` |
| `0x1FFFF7F0` | `R32_ESIG_UNIID3` | `U_ID[95:64]` |

拼接顺序为 UNIID1 → UNIID2 → UNIID3（与沁恒例程的打印顺序一致；顺序只是约定，
不影响唯一性）。同一份字符串同时供两处使用：

- USB 描述符的 iSerialNumber（`dap_main.c` 的 `string_descriptors[3]`）
- CMSIS-DAP 的 `DAP_GetSerNum` 命令（`src/dap/DAP_config.h` 的 `DAP_GetSerNumString()`）

两点注意：

1. **打开后会改变主机侧的设备实例**。USB 序列号参与 Windows 的设备枚举与驱动匹配，
   换了序列号等于换了一台设备，首次插入需要重新匹配一次驱动（本设备是 WinUSB，
   靠 MS OS 2.0 描述符自动匹配，无需手工安装）。原来绑定 `DEADBEEF` 实例的
   OpenOCD / pyOCD 配置需要用新序列号。
2. **UID 读不出来时会退回固定串**。若三个寄存器读回全 0 或全 FF（地址不对、
   ESIG 不可读等），固件不会把「看似唯一、其实所有板子都相同」的串当序列号发出去，
   而是退回 `DEADBEEF`，让「没生效」在主机侧可见。（本工程 `_write` 是空实现，
   没有日志可用，所以只能靠这个现象判断。）

`--esig_sn=y` 需要 `--dap=y`：序列号在 `src/dap/dap_main.c` 里设置，而该文件只在
启用 CMSIS-DAP 时编译。这个组合会被 `xmake.lua` 与 `build.ps1` 直接拒绝，
不会默默编出一个用不上它的固件。

### 与参考工程的两处必要差异

这两处都是参考工程 `ch32x035-usb-dap-main` 里不存在的构建陷阱，已在本工程解决：

1. **`bool` 未定义**：CherryUSB 的 `class/cdc/usbd_cdc_acm.h` 用了 `bool` 但自己没包含
   `<stdbool.h>`，而 `dap_main.h` 里 `usbd_cdc.h` 排在 `usbd_core.h`（内含 `<stdbool.h>`）
   之前。参考工程是**直接改了 cherryusb 子模块**（它的子模块处于 dirty 状态），
   本工程不改 submodule，把 `#include <stdbool.h>` 放在自己的 `src/dap/dap_main.h` 里。
   **升级 cherryusb submodule 时需重新确认这一点是否已在上下游修好。**
2. **`Delay_Init` / `Delay_Us` 未定义**：本工程不编译 `sdk/Debug/debug.c`
   （它无条件定义 `_write` / `_sbrk`，与 `src/bsp/bsp_print.c` 的 retarget 冲突），
   但本 SDK 版本的 `sdk/Peripheral/src/ch32x035_pwr.c` 里
   `PWR_VDD_SupplyVoltage()` 会调用这两个函数（参考工程用的旧版 SDK 没有这两行，
   而且它也从不调用该函数，所以没暴露问题）。已在 `src/bsp/bsp_delay.c` 末尾提供
   转发到 SysTick 延时 的等价实现。

## 第三方依赖

```sh
git submodule update --init
```

三个 submodule 固定在以下版本：

| submodule | commit |
| --- | --- |
| cherryusb | `0e40349` (v1.6.1-82) |
| cherryrb | `19ea7c6` (v1.0.0) |
| cherrydap | `c40bb5a` (HSLinkPro-2.4.2-41) |

## 构建

需要 WCH RISC-V GCC 工具链：设置 `WCH_TOOLCHAIN_ROOT`，或安装 MounRiver Studio 2
由 `toolchains/wch-riscv/xmake.lua` 自动探测默认路径。

```powershell
# 便捷脚本（release，DAP 默认启用）
.\build.ps1
.\build.ps1 -Dap n          # 关闭 CMSIS-DAP，只编 USB 骨架
.\build.ps1 -EsigSn y       # 用芯片 ESIG UID 作序列号（每颗芯片唯一）
.\build.ps1 -Clean          # 先清理
.\build.ps1 -Mode debug     # debug 构建
.\build.ps1 -Reconfigure    # 工具链路径变化后强制重新配置

# 或直接用 xmake
$env:WCH_TOOLCHAIN_ROOT = "D:/program/wch/MounRiver_Studio2/resources/app/resources/win32/components/WCH/Toolchain/RISC-V Embedded GCC12"
xmake f -m release -y
xmake -r

# 关闭 CMSIS-DAP，只编 USB 骨架
xmake f -m release --dap=n -y
xmake -r

# 用芯片 UID 作序列号
xmake f -m release --dap=y --esig_sn=y -y
xmake -r
```

产物：`build/<mode>/firmware.elf`、`firmware.bin`、`firmware.map`。构建结束会打印
Flash / RAM 占用统计。

链接脚本为 `sdk/Ld/Link_highcode_nv_256B.ld`：Flash 62K（末尾 256B 留给 NV 配置），
RAM 20K；`.highcode` 段由 `startup_ch32x035_highcode.S` 在启动时从 Flash 搬到 RAM 执行，
USB 设备端口等热路径代码通过 `section(".highcode")` 放在其中。

## 当前状态

USB（CherryUSB + CH32X035 端口 glue + 硬件初始化）与 CMSIS-DAP（CherryDAP + 本板
DAP glue）都已编译链接成功，并经实测确认：USB 正常枚举（CMSIS-DAP 调试器 + CDC 串口
同时出现），DAP 能通过 OpenOCD 对目标读写（140 KiB/s 量级，见下方「验证」）。

**注意：`src/dap/DAP_config.h` 的 SWD / nRESET 引脚是按参考工程
`ch32x035-usb-dap-main` 直接搬过来的（SWCLK=PA2、SWDIO=PA3、nRESET=PA5），
尚未按 uDap2 原理图核对，上板前必须确认。**

| 项目 | 取值 | 需核对 |
| --- | --- | --- |
| SWCLK / SWDIO | PA2 / PA3 | ✓ |
| nRESET | PA5 | ✓（见下方说明） |
| 桥接串口 | USART4：PB0=TX、PB1=RX | ✓ |
| 状态灯 | PB12，高电平点亮，接 `LED_CONNECTED_OUT` | ✓ |
| USB | PC16=UDM / PC17=UDP | 固定复用，无选择余地 |

### 状态指示灯

本板只有一颗灯（PB12，高电平点亮），接的是 CMSIS-DAP 的 **Connect LED**：主机连接到
DAP 时点亮、断开时熄灭。改脚或改极性只需动 `src/dap/DAP_config.h` 里的三个宏：

```c
#define LED_CONNECTED_PORT         GPIOB
#define LED_CONNECTED_PIN          GPIO_Pin_12
#define LED_CONNECTED_ACTIVE_HIGH  1U   // 0 = 低电平点亮
```

它由主机下发的 `ID_DAP_HostStatus(0x01)` 驱动（DAP.c 的 `DAP_HostStatus`）：

| 状态类型 | 固件回调 | 主机行为 |
| --- | --- | --- |
| `DAP_DEBUGGER_CONNECTED`(0) | `LED_CONNECTED_OUT` | pyOCD 在 `connect()` 置 1、`disconnect()` 置 0 |
| `DAP_TARGET_RUNNING`(1) | `LED_RUNNING_OUT` | pyOCD **从不置 1**（只下发 0），OpenOCD 不发该命令 |

因此 `LED_RUNNING_OUT` 保持空实现（本板也没有第二颗灯）。**这意味着灯的可见性取决于
主机工具**：pyOCD 下会亮；OpenOCD 若不支持该命令则始终不亮 —— 这种情况需要固件本地
指示（如 USB 枚举后常亮），目前未实现。

> ⚠️ **参考工程自身的 README 与代码不一致**：它的 `README.md` 引脚表写
> `PB12 = nRESET`、`PA5 = 按键`，但 `src/dap/DAP_config.h` 里是 `PA5 = nRESET`
> （它的提交记录 `将pa5作为rst引脚` 改了代码却漏改文档）。本工程照搬的是**代码**
> （PA5），不是它的 README。若本板 PA5 另有用途，必须改 `DAP_config.h`。

## 验证

固件烧录后，主机应能看到一个 CMSIS-DAP 调试器和一个 CDC 串口。可用：

```sh
probe-rs list
probe-rs info --chip <目标型号> --probe <CMSIS-DAP探针序列号>
```

USB 描述符沿用 CherryDAP 示例的 VID/PID `0d28:0204`。序列号默认固定为 `DEADBEEF`，
可用 `--esig_sn=y` 改成芯片出厂 UID（见上方「序列号」一节）。

本工程自带 `tools/` 下的测速与串口测试脚本（与参考工程一致）：

```powershell
.\tools\speed.ps1 -Khz 6000 -Bytes 65536 -Rounds 3

# 频率扫描（一次跑 100 kHz ~ 12 MHz 并汇总）
.\tools\openocd_speed_sweep.ps1 -Rounds 5 -Warmup 1

# 串口环回吞吐 / 利用率（需 PB0-PB1 短接）
python .\tools\com_loopback_speed.py --seconds 2 --repeats 3

# 分块 / 间隔发送（撤除波特率上限后新增）
python .\tools\com_loopback_paced.py --baud 2000000 --chunk 4096 --total 262144
python .\tools\com_loopback_matrix.py --baud 2000000,3000000 --chunk 192,4096
```

实测基线（STM32F411 目标，OpenOCD + `tools/openocd_speed_test.tcl`，2026-09-26，
16 KiB 块、预热 1 轮 + 5 轮平均）：

| SWCLK | 写 KiB/s | 读 KiB/s | 路径 |
| --- | --- | --- | --- |
| 4000 kHz | 54.2 | 45.3 | 慢（已饱和） |
| 5750 kHz | 54.1 | 45.5 | 慢（饱和，最后一档） |
| **6000 kHz** | **125.4** | **121.0** | **快（拐点）** |
| 12000 kHz | 126.3 | 119.0 | 快（与 6 MHz 同速） |

慢路径自约 2.5 MHz 起完全饱和（2.5 → 5.75 MHz 都在 54 / 45 KiB/s），
6 MHz 跨过 `MAX_SWJ_CLOCK(2)` 阈值切到快路径后约 2.3 倍。
**快路径的实际 SWCLK 由固定指令数决定（约 6 MHz），所以填 6 MHz 和填 12 MHz 速度相同 ——
推荐就填 6 MHz**（阈值处余量最厚）。

阈值可在 `src/dap/DAP_config.h` 里用 `DELAY_FAST_CYCLES` 调整
（阈值 = `24 MHz / (2 + DELAY_FAST_CYCLES)`，本工程 2 → 6 MHz；上游默认 0 → 12 MHz）。
`tools/speed.ps1` 与 `openocd_speed_sweep.ps1` 的 `-FastMinKhz`（默认 6000）
只影响打印的路径标注，**改固件阈值时需同步**。

COM 口波特率不再有上限（原先 `> 2 Mbaud` 会被 STALL，已撤除，见 `src/dap/dap_main.c`
里「关于 COM 口波特率」的说明）。实测桥接吞吐天花板约 **190~200 KiB/s**，
2 Mbaud 就处在天花板上；再提高波特率换不来吞吐，反而要求把发送块压到 ≤192 B
才能不丢字节。**完整频率表、串口环回利用率、波特率 × 块大小矩阵与可靠性边界，
见仓库根目录的 `readme.md` 第 6 节。**

**比较两版固件速度时必须确保 `-Khz` 相同**：≥6000 kHz 才走「快路径」，差 2.3 倍。
注意 PowerShell 参数要写成 `-Khz 6000` 或 `-Khz:6000`，写成 `-Khz=6000` 会直接报错
（已加 `[CmdletBinding()]` 拦截，避免静默回落到默认的 4000 kHz）。

## 其他可参考的实现

本仓库内**不再包含**这两个参考工程（用完后已移出）；以下按名称记录，需要时自行取用。

| 工程 | 技术路线 | 可参考部分 |
| --- | --- | --- |
| `ch32x035-usb-dap-main` | CherryUSB + CherryRB + CherryDAP | 本工程 glue（`src/dap`、`src/drv`、`src/bsp`）的来源 |
| `CH32X035F8U`（CheapLink_X035） | WCH USBFS 驱动 + FreeRTOS | PIOC 加速（SWD 提速）、AIRCR 复位序列、TIM3 时间戳、三色 LED 状态机 |

`CH32X035F8U`（CheapLink_X035）的 SWD 引脚是 PA5/PA6/PA7 加 PIOC 的 PC18/PC19，
与本工程当前取值不同；若最终采用 PIOC 方案，需按它重写 `DAP_config.h` 的引脚宏与
`PORT_SWD_SETUP()`。以 uDap2 原理图 `hardware/uDap.kicad_sch` 为准。

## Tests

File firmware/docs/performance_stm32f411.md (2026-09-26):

# SWD 性能基准（STM32F411 目标）

本文件记录本 DAP 固件在 **STM32F411CEU6** 目标上的烧录速度实测值，用于：
- 回归对比（改时序/DAP 代码后跑一遍，看有没有退化）
- 判断瓶颈在哪一侧（DAP 链路 vs 目标 Flash 控制器）
- 定位慢/快路径切换点

## 基线快照

| 项目 | 值 |
| --- | --- |
| 日期 | 2026-09-22 |
| git HEAD | `8d747e0` |
| 工作区改动 | `src/dap/DAP_config.h`、`src/dap/sw_dp.c` |
| `firmware.bin` | 20916 bytes，sha256 前缀 `37FBAAA35D5C43C8` |

固件关键时序参数（`src/dap/DAP_config.h`）：

| 参数 | 值 | 说明 |
| --- | --- | --- |
| `CPU_CLOCK` | 48 MHz | CH32X035 HSI |
| `IO_PORT_WRITE_CYCLES` | 2 | |
| `DELAY_SLOW_CYCLES` | 8 | 慢路径延时系数（原 3，配合非 volatile 紧凑循环） |
| `SWD_FAST_DELAY_NOPS` | 1 | 快路径余量 NOP；**必须 ≥1**，否则有负载时 ACK 错误 |

快路径切换阈值 `MAX_SWJ_CLOCK(0) = (48M/2)/(2+0) = 12 MHz`，**刻意保持 12 MHz 不变**。

> ⚠️ **此决定已于 2026-09-26 推翻**（见文末「后续变更」）：阈值已改为 **6 MHz**。
> 本文件其余数据是 2026-09-22 那个固件版本的基线快照，**保留原值作为回归参照**，
> 但「12 MHz 起跳」的说法只对旧版本成立 —— 新版本 6 ~ 11.5 MHz 也走快路径，
> 那几档的速度会变成快路径的 ~125 KiB/s（而不再是慢路径的 ~54）。

## 测试环境

| 项目 | 值 |
| --- | --- |
| 目标 | STM32F411CEU6，IDCODE `0x2BA01477` |
| 目标 Flash | 512 KiB @ `0x08000000`，8 扇区（4×16K + 1×64K + 3×128K） |
| 目标 SRAM | 128 KiB @ `0x20000000` |
| 主机工具 | OpenOCD 0.12.0（MRS2 内置）、pyocd 0.45.1 |

被测探针有两块，下文数据会标注是哪一块：

| 代号 | 探针 | 唯一 ID | 备注 |
| --- | --- | --- | --- |
| **本板 DAP** | CH32X035 DAP（本仓库固件） | `00000000000000000123456789ABCDEF` | CMSIS-DAP v1 |
| **Air32** | LuatOS Air32 MINI DAPLink | `000100011a5a5bb6000000000003f60fa5a5a5a597969908` | CMSIS-DAP **v2**（bulk），固件 0258，协议 2.1.0；频率上限 **17.5 MHz**（18 MHz 起失败） |

> 注意：两块探针的 VID:PID 都是 `0d28:0204`，同时插入时需用 `-u <serial>` 或 `probe-rs` 的序列号区分。

## RAM 写入速度（本板 DAP）

纯数据搬运，**瓶颈完全在 DAP 侧的 SWD 链路**，是衡量链路性能的干净指标。

命令：

```powershell
python tools/pyocd_ram_speed.py -t stm32f411ce --sizes 64K `
    --frequencies 1000k,2000k,3000k,4000k,8000k,11500k,12000k,16000k,20000k,40000k `
    --repeats 5
```

64 KiB @ `0x20000000`，5 轮取中位数，`program` 模式（FileProgrammer）：

| SWD 请求 | 耗时 | 写入速度 | 路径 |
| --- | --- | --- | --- |
| 1 MHz | 2361.5 ms | 27.1 KiB/s | 慢 |
| 2 MHz | 1752.0 ms | 36.5 KiB/s | 慢 |
| 3 MHz | 983.6 ms | **65.1 KiB/s** | 慢（已饱和） |
| 4 MHz | 983.5 ms | 65.1 KiB/s | 慢（饱和） |
| 8 MHz | 983.5 ms | 65.1 KiB/s | 慢（饱和） |
| 11.5 MHz | 983.7 ms | 65.1 KiB/s | 慢（饱和） |
| **12 MHz** | 303.4 ms | **210.9 KiB/s** | **快（拐点）** |
| 16 MHz | 305.4 ms | 209.5 KiB/s | 快 |
| 20 MHz | 311.1 ms | 205.7 KiB/s | 快 |
| 40 MHz | 330.5 ms | 193.7 KiB/s | 快 |

补充：`--mode raw`（直调 `write_memory_block8`）在 12 MHz 下为 **215.1 KiB/s**，
比 `program` 模式快约 17%。原因是 `RamBuilder._MAX_WRITE_SIZE = 4096`，
`program` 模式按 4 KiB 分包，每包都有一次往返开销。**想测链路上限用 `--mode raw`。**

### 观察

- 慢路径从 3 MHz 起完全饱和：3/4/8/11.5 MHz 耗时差 < 0.2 ms。因为 `clock_delay`
  被钳到最小值，请求更高频率不会有任何变化。
- 快路径 12~40 MHz 全落在 194~211 KiB/s。**快路径实际 SWCLK 是固定的 ~6 MHz**，
  由指令执行时间决定，与请求频率无关，所以填 12 还是 40 MHz 结果相同；
  差别只是余量厚度。
- 12 → 40 MHz 反而略慢（210.9 → 193.7），说明请求越高余量越紧，宁可填 12。

## RAM 读写速度（Air32 MINI DAPLink）

测量日期 2026-09-22，同一颗 F411 目标。主测工具为 `tools/openocd_speed_test.tcl`，
并用 pyocd 两条路径交叉验证。这块探针的特性：

- **对 SWD 频率只有弱依赖**：1 MHz 明显偏低（~90 KiB/s），2 MHz 以上进入平台期
  （120~172）。主要瓶颈在 **USB 传输路径**，不在 SWD 时钟。这点和本板 DAP 不同
  （本板 DAP 在 3 MHz 饱和、12 MHz 起跳 2.8 倍）。
- **读写几乎对称**（读/写 = 0.96~1.06），两个方向受同一瓶颈支配。
- **块大小以 8~16 KiB 最优**，≥32 KiB 反而下降。这是本探针的独有特征。
- **吞吐本身极不稳定**：完全相同的配置，实测 85~172 KiB/s（约 2x），
  且 5 分钟冷却不能恢复（见「稳定性」）。**单次测量不可用。**

### 主测：OpenOCD 频率扫描

```powershell
openocd -f interface/cmsis-dap.cfg -f target/stm32f4x.cfg `
  -c "set speed_khz 8000; set test_bytes 65536; set rounds 10; set warmup_rounds 2" `
  -c "source tools/openocd_speed_test.tcl"
```

64 KiB @ `0x20000000`，10 轮取平均。同一频率连跑 3 次以观察波动（单位 KiB/s）：

| SWD 请求 | 写（3 次） | 写中位 | 读（3 次） | 读中位 |
| --- | --- | --- | --- | --- |
| 1 MHz | 105.1 / 100.5 / 83.4 | 100.5 | 101.3 / 97.6 / 83.0 | 97.6 |
| 2 MHz | 133.5 / 126.7 / 120.2 | 126.7 | 132.1 / 126.5 / 120.4 | 126.5 |
| 4 MHz | 149.2 / 154.9 / 127.6 | 149.2 | 149.8 / 153.4 / 125.4 | 149.8 |
| 8 MHz | 168.1 / 161.0 / 97.8 | 161.0 | 164.6 / 159.0 / 97.0 | 159.0 |
| 12 MHz | 163.5 / 158.3 / 84.5 | 158.3 | 162.2 / 156.9 / 86.4 | 156.9 |
| 16 MHz | 164.3 / 170.6 / 128.8 | 164.3 | 164.5 / 171.0 / 126.4 | 164.5 |
| 17.5 MHz | 165.3 / 159.2 / 131.7 | 159.2 | 164.0 / 156.8 / 130.5 | 156.8 |

注意每个频率的第 3 次普遍偏低 —— 这是随机波动，不是趋势（下节有专门验证）。

独立扫描 5 轮，取 最小 / 中位 / 最大 更能体现波动幅度：

| SWD 请求 | 写 最小 / 中位 / 最大 | 读 最小 / 中位 / 最大 |
| --- | --- | --- |
| 1 MHz | 85.0 / 90.0 / 95.1 | 84.4 / 89.3 / 93.3 |
| 2 MHz | 83.0 / 95.0 / 127.4 | 83.8 / 95.0 / 126.4 |
| 4 MHz | 96.0 / 119.4 / 135.1 | 96.1 / 118.2 / 134.2 |
| 8 MHz | 115.7 / 134.6 / 142.6 | 113.6 / 132.1 / 142.1 |
| 12 MHz | 113.7 / 135.3 / 148.7 | 104.1 / 134.1 / 143.9 |
| 16 MHz | 100.6 / 118.0 / 144.1 | 99.2 / 116.8 / 140.0 |
| 17.5 MHz | 86.7 / 114.6 / 146.1 | 86.5 / 113.8 / 143.8 |

频率曲线（取中位）：

```
 1 MHz  ▏████████████████████▎               90.0    ┐
 2 MHz  ▏█████████████████████▏                95.0   │ 低频段（1 MHz 明显低）
 4 MHz  ▏██████████████████████████▌          119.4    ┘
 8 MHz  ▏██████████████████████████████▏      134.6    ┐
12 MHz  ▏███████████████████████████████▏     135.3    ├ 平台段（频率无增益）
16 MHz  ▏██████████████████████████▎          118.0    │
17.5MHz ▏█████████████████████████▌           114.6    ┘
```

### 块大小的影响

8 MHz，每档跑两次取最大值：

| 块大小 | 写 | 读 | 读/写 |
| --- | --- | --- | --- |
| 1 KiB | 145.7 | 154.5 | 1.06 |
| 2 KiB | 164.8 | 163.7 | 0.99 |
| 4 KiB | 161.0 | 158.5 | 0.98 |
| **8 KiB** | **171.4** | **169.6** | 0.99 |
| **16 KiB** | 168.5 | 165.7 | 0.98 |
| 32 KiB | 151.9 | 148.3 | 0.98 |
| 64 KiB | 141.9 | 136.6 | 0.96 |
| 96 KiB | 128.4 | 125.8 | 0.98 |

**8~16 KiB 是最优块大小。** 1 KiB 太小（协议开销占比高），
≥32 KiB 反而下降（64→96 KiB 降了 10~13%）。这和本板 DAP 相反 ——
本板 DAP 是块越大越好（`RamBuilder._MAX_WRITE_SIZE = 4096` 反而拖慢了 program 模式）。
所以测这块探针时，**块大小比 SWD 频率更值得调**。

### 交叉验证：pyocd 同会话交替测读写

若「写」和「读」分别在两个会话里测，差异可能纯粹来自会话状态
（这块探针的会话间波动比读写差异还大）。因此在一次连接内交替执行
写-读-写-读…，用 `tools/pyocd_ram_rw_compare.py`：

```powershell
python tools/pyocd_ram_rw_compare.py -f 1000k,2000k,4000k,8000k,12000k,16000k,17500k --pairs 8
```

64 KiB @ `0x20000000`，`write_memory_block8` / `read_memory_block8`，每频率 8 组：

| SWD 请求 | 写 中位 | 读 中位 | 读/写 |
| --- | --- | --- | --- |
| 1 MHz | 96.3 KiB/s | 103.4 KiB/s | 1.07x |
| 2 MHz | 102.9 KiB/s | 120.0 KiB/s | 1.17x |
| 4 MHz | 96.2 KiB/s | 109.8 KiB/s | 1.14x |
| 8 MHz | 124.1 KiB/s | 135.8 KiB/s | 1.09x |
| 12 MHz | 98.2 KiB/s | 110.1 KiB/s | 1.12x |
| 16 MHz | 91.6 KiB/s | 104.0 KiB/s | 1.14x |
| 17.5 MHz | 95.7 KiB/s | 109.2 KiB/s | 1.14x |

重复一轮（15 组）后读/写比仍为 **0.97x / 1.19x / 1.18x**，
绝对值在 110~144 之间 —— 和 OpenOCD 主测结论一致（读≈写，平台期）。

## 稳定性：为什么单次测量不可用

同一频率连续测多次，结果会在 **~90 KiB/s 和 ~200 KiB/s 两档之间跳**，
不是逐渐退化，也不是测量噪声（会话内极差只有 1.2~1.5x）。
例如 8 MHz 写连续 8 次：

```
124.3   205.8   210.6   199.7    97.5   103.8   217.9   212.6  KiB/s
```

前 4 次和后 2 次是「快档」，中间 2 次掉到「慢档」。相同现象在 OpenOCD 主测里
表现为「每频率第 3 次偏低」（见上表）—— 不是工具差异，是探针本身的行为。

**已排除热效应**：静置 5 分钟后再测，吞吐反而更低（95.8），紧接着又跳到 138.7：

```
冷却前        : 120.33 KiB/s
静置 5 分钟后 :  95.84 KiB/s   <- 没恢复，说明不是过热降频
紧接着        : 138.73 KiB/s   <- 立刻又变快，进一步排除热
```

**已排除主机负载**：测试时无残留进程，20 核 CPU 平均负载 33%。

原因仍未定位，怀疑与 USB 主机侧调度有关（该探针为 CMSIS-DAP **v2** bulk 传输，
而本板 DAP 是 v1 HID —— v1/v2 的差异可能是原因之一）。

**结论：测这块探针必须多采样、报中位数与极差，单次结果不可用。**
这也是为什么 `pyocd_ram_speed.py` 现在会同时打印 最快/最慢/极差。

## 探针对比：本板 DAP vs Air32

| 场景 | 本板 DAP | Air32 | 胜者 |
| --- | --- | --- | --- |
| 1 MHz 写（pyocd） | 27.1 KiB/s | **96.3** KiB/s | Air32（3.6x） |
| 12 MHz 写（pyocd） | **210.9** KiB/s | 98.2 KiB/s | 本板 DAP（2.1x） |
| 12 MHz 写（OpenOCD 主测） | 115.3 KiB/s | ~158 KiB/s | Air32 |
| 16 MHz 写（OpenOCD 主测） | 122.8 KiB/s | ~164 KiB/s | Air32 |
| 峰值写（OpenOCD） | ~123 KiB/s | **~172 KiB/s** | Air32（1.4x） |
| 频率依赖 | 强（3 MHz 饱和 / 12 MHz 跳变 2.8x） | 弱（2 MHz 以上平台） | — |
| 块大小依赖 | 越大越好 | **8~16 KiB 最优** | — |
| 测量稳定性 | 稳定（极差 1.2~1.5x） | **不稳定（极差 2x）** | 本板 DAP |
| 频率上限 | ≥40 MHz | 17.5 MHz | 本板 DAP |

四个要点：

1. **低频时 Air32 快得多**（1 MHz 下 3.6x）。本板 DAP 的慢路径在 3 MHz 就饱和
   （`clock_delay` 钳位），而 Air32 不受 SWD 时钟限制。
2. **pyocd 下高频本板 DAP 反超**（12 MHz：210.9 vs 98.2），但 **OpenOCD 下 Air32 反超**（158 vs 115）。
   两个工具给出相反结论，因为它们的最优工作点不同 —— pyocd 用大块传输会碰到
   Air32 的「≥32 KiB 降速」问题，而本板 DAP 正好相反。
3. **公平对比必须各自调到最优块大小**。Air32 在 OpenOCD 下把块从 64 KiB 改成 8 KiB
   就能从 ~142 提到 ~172；本板 DAP 在 OpenOCD + 64 KiB 下只有 115~123，
   但 pyocd 大块能到 210.9 —— 说明 **OpenOCD 对大块传输的处理不如 pyocd**。
   所以「哪块探针更快」取决于工具与块大小的组合，不能只看一组配置。
   （本板 DAP 在 OpenOCD 下的小块表现未测试，暂无数据）
4. **稳定性差异很大**。本板 DAP 可重复（极差 1.2~1.5x）；Air32 有 2x 随机跳跃，
   且不受冷却影响 —— 做性能对比时要多采样。

## Flash 烧录速度（本板 DAP）

命令（分离擦除/写入/校验三个阶段，500 KiB 随机数据）：

```powershell
openocd -s <openocd scripts> -f interface/cmsis-dap.cfg -f target/stm32f4x.cfg `
  -c "set speed_khz 12000; set image build/testdata/rand500k.bin; set flash_addr 0x08000000" `
  -c "source tools/openocd_flash_speed_test.tcl"
```

512000 bytes @ `0x08000000`，扇区 0~7 全擦：

| SWD 请求 | 擦除 | 写入 | 校验 | 总计 | 写入速度 | 整体速度 |
| --- | --- | --- | --- | --- | --- | --- |
| 1 MHz | 8203 ms | 22244 ms | 3769 ms | 34216 ms | 22.5 KiB/s | 14.6 KiB/s |
| 2 MHz | 8103 ms | 17366 ms | 3753 ms | 29222 ms | 28.8 KiB/s | 17.1 KiB/s |
| 4 MHz | 8189 ms | 11360 ms | 3740 ms | 23289 ms | 44.0 KiB/s | 21.5 KiB/s |
| 8 MHz | 8309 ms | 11051 ms | 3736 ms | 23096 ms | 45.2 KiB/s | 21.6 KiB/s |
| 11.5 MHz | 8046 ms | 10701 ms | 3735 ms | 22482 ms | 46.7 KiB/s | 22.2 KiB/s |
| **12 MHz** | 8039 ms | **4377 ms** | 3717 ms | **16133 ms** | **114.2 KiB/s** | **31.0 KiB/s** |
| 16 MHz | 8162 ms | 4383 ms | 3714 ms | 16259 ms | 114.1 KiB/s | 30.7 KiB/s |
| 20 MHz | 8138 ms | 4400 ms | 3715 ms | 16253 ms | 113.6 KiB/s | 30.8 KiB/s |

写入速度曲线：

```
 1 MHz  ▏█████▎                                    22.5 KiB/s
 2 MHz  ▏██████▊                                   28.8
 4 MHz  ▏██████████▍                               44.0
 8 MHz  ▏██████████▋                               45.2   ┐ 慢路径饱和
11.5MHz ▏███████████                               46.7   ┘
12 MHz  ▏██████████████████████████▋              114.2   ← 拐点，2.4x
16 MHz  ▏██████████████████████████▋              114.1
20 MHz  ▏██████████████████████████▍              113.6
```

### 观察

- **擦除恒定 ~8.1 s**（8039~8309 ms，抖动 < 3%），与 SWD 时钟完全无关。
  这是 F411 片上 Flash 控制器的固定成本，DAP 再快也压不动。
- **写入在 12 MHz 跳变 2.4 倍**（46.7 → 114.2 KiB/s），拐点位置与 RAM 完全一致。
- **校验 ~3.7 s / 133 KiB/s**，同样不随 SWD 时钟变化 —— 校验是读操作，
  受 DAP 读带宽限制（~134 KiB/s），而非目标。
- 12 → 20 MHz 写入只差 0.5%，**没有理由往上写**。

## RAM vs Flash 对比（12 MHz）

| | 写入速度 | 瓶颈 |
| --- | --- | --- |
| **RAM** | 210.9 KiB/s | DAP 侧 SWD 链路 |
| **Flash** | 114.2 KiB/s | 目标 Flash 编程时间 |
| 比值 | **1.85×** | |

Flash 写入被目标每页编程后的等待拖住，所以比纯搬运的 RAM 慢近一倍。
**要评估 DAP 链路本身，应看 RAM 数据；Flash 数据还混了目标特性。**

## 结论

### 本板 DAP（CH32X035）

1. **12 MHz 是唯一实用档位**。慢路径在 3 MHz 就饱和（RAM 65.1 / Flash 46.7 KiB/s），
   而快路径在 12 MHz 起跳（RAM 210.9 / Flash 114.2 KiB/s），12 到 40 MHz 无增益甚至略降。
   *（本条**只对 2026-09-22 那版固件成立**；新版本阈值已降到 6 MHz，
   6 MHz 起就是快路径速，不必填 12 —— 见文末「后续变更」。）*
2. **快路径实际约 6 MHz**，请求值只影响余量、不影响速度。
   快路径余量必须保留 `SWD_FAST_DELAY_NOPS=1`。
3. **Flash 擦除是硬下限**：500 KiB 场景下擦除占 ~8.1 s，是总时间的 50%（12 MHz）。
   SWD 提速只能优化写入段的 ~4.4 s。

### Air32 MINI DAPLink

4. **吞吐对 SWD 频率只有弱依赖**：1 MHz 偏低（~90），2 MHz 以上平台（~120~172）。
   瓶颈在 USB 传输路径，所以调高 SWD 频率没用。频率实际上限 17.5 MHz。
5. **块大小以 8~16 KiB 最优**，≥32 KiB 反而下降 10~13%。这比调频率更值得调。
6. **读写几乎对称**（读/写 = 0.96~1.06），两个方向受同一瓶颈支配。
7. **吞吐有 ~2x 随机跳跃**，且**已排除热效应**（静置 5 分钟不恢复）与主机负载。
   测这块探针必须多采样并报中位数 + 极差，单次数据不可用。

### 通用

6. **不要用 pyocd 报告的 `at X kB/s`**，见下节。
7. **同一工具下块大小的影响可能大于换探针**。Air32 在 OpenOCD 下 64 KiB→8 KiB 提升 21%；
   本板 DAP 在 pyocd 下 program→raw 提升 17%。做性能结论前先确认块大小已调到最优。

## 注意：pyocd 的 "at X kB/s" 不可信

pyocd 日志：

```
Erased 65536 bytes (4 sectors), programmed 51200 bytes (50 pages), identical 0 bytes (0 pages) at 23.67 kB/s
```

该速度 = `program_byte_count / (erase_time + program_time)`（见 `pyocd/flash/loader.py`
的 `_log_performance`）。当写入数据与 Flash 现有一致时，smart_flash 会跳过擦除与编程，
**分母塌掉、分子照旧**，数字虚高数倍。

判据：**出现 `Erased 0 bytes (0 sectors)` 即为跳过烧录，该速度无意义。**

| 50 KiB @12 MHz | 编程耗时 | 速度 |
| --- | --- | --- |
| 真实烧录 | 743 ms | 68.9 KiB/s |
| 跳过烧录 | — | 160.67 kB/s（虚高，实为读回带宽） |

强制真实烧录：加 `-O smart_flash=False`，或每次换一份随机数据。

## 复现

| 测试 | 命令 |
| --- | --- |
| RAM 速度（写） | `python tools/pyocd_ram_speed.py -t stm32f411ce --sizes 64K --frequencies 12000k --repeats 5` |
| RAM 速度（读） | 同上加 `--mode read` |
| RAM 链路上限 | 同上加 `--mode raw` |
| RAM 读写同会话对比 | `python tools/pyocd_ram_rw_compare.py -f 8000k --pairs 12` |
| 吞吐波动诊断 | `python tools/pyocd_ram_variance.py -f 8000k --samples 20 --sessions 3` |
| RAM 读写（OpenOCD） | `-c "set speed_khz 8000; set test_bytes 8192; set rounds 10"` + `source tools/openocd_speed_test.tcl` |
| Flash 速度（分离阶段） | `-c "set image build/testdata/rand500k.bin"` + `source tools/openocd_flash_speed_test.tcl` |
| pyocd 真实 vs 跳过对照 | `pwsh -File tools/pyocd_cli_flash_sweep.ps1` |
| 指定探针 | 加 `-u <serial>`，两块探针 VID:PID 相同 |

> 测 Air32 时把 `test_bytes` 改成 8192~16384 可拿到峰值（见「块大小的影响」）。

测试数据生成：

```powershell
python -c "import random;open('build/testdata/rand500k.bin','wb').write(random.Random(0x20260922).randbytes(512000))"
```

> 提示：500 KiB 测试会覆盖目标 `0x08000000` 起全部 8 个扇区，
> **测试后目标的原固件需要重新烧录。**

---

## 后续变更

### 2026-09-26：快路径阈值 12 MHz → 6 MHz

上面的基线是「12 MHz 才起跳」。这个阈值其实**不是硬编码在代码里的常量**，而是
CherryDAP 的一个可配宏算出来的（`DAP/Source/DAP.c` 的 `Set_Clock_Delay()`）：

```c
#define MAX_SWJ_CLOCK(delay_cycles)  ((CPU_CLOCK/2U) / (IO_PORT_WRITE_CYCLES + delay_cycles))
if (clock >= MAX_SWJ_CLOCK(DELAY_FAST_CYCLES)) { fast_clock = 1; ... }
```

所以把 `DAP_config.h` 里的 `DELAY_FAST_CYCLES` 从默认 `0` 改成 `2`：

$$\text{阈值}=\frac{48\,\text{MHz}/2}{2+2}=6\,\text{MHz}$$

**为什么改**：快路径的实际 SWCLK 由固定指令数决定（约 6 MHz），**与请求值无关** ——
请求 6 MHz 和请求 12 MHz 拿到同一个速率。阈值留在 12 MHz 的唯一后果，是让主机填
6 ~ 11.5 MHz 时白跑慢路径。实测确认（16 KiB 块，5 轮平均）：

| SWCLK 请求 | 写 KiB/s | 读 KiB/s | 路径 |
| ---: | ---: | ---: | :--- |
| 5000 kHz | 53.3 | 45.1 | 慢（饱和） |
| 5750 kHz | 54.1 | 45.5 | 慢（饱和，最后一档） |
| **6000 kHz** | **125.4** | **121.0** | **快（拐点）** |
| 12000 kHz | 126.3 | 119.0 | 快（与 6 MHz 同速） |

反汇编交叉验证（LTO 把 `Set_Clock_Delay` 内联进了 `DAP_ProcessCommand`）：

```asm
20002460:  lui  a5,0x5b9
20002464:  addi a5,a5,-641      ; a5 = 5 999 999
20002468:  bltu a5,a4, <快路径>  ; clock > 5999999 → 快路径
```

即阈值正好是 6 000 000 Hz；慢路径的延时算法（`(d-2+7)/8`）逐字未变。

**`DELAY_FAST_CYCLES` 的第二个用途**（决定 `PIN_DELAY_FAST()` 补几个 NOP）在本工程
不受影响：`src/dap/sw_dp.c` 已把 `PIN_DELAY_FAST` 重定义为固定一个 `__NOP()`，
且上游唯二使用它的 `SW_DP.c` / `JTAG_DP.c` **未参与编译**（`xmake.lua` 只编
`DAP.c` + `DAP_vendor.c`）。所以该宏在本工程里**纯粹是阈值旋钮**，零时序副作用。

**`SWD_FAST_DELAY_NOPS=1` 的要求仍然成立**（快路径余量）—— 这一点没有变。

**顺带修的一个坑**：`tools/speed.ps1` 与 `tools/openocd_speed_sweep.ps1` 原先把
「≥12000 kHz 是快路径」**硬编码**在打印逻辑里，改阈值后它们会打出错误的路径标注。
现已改成参数 `-FastMinKhz`（默认 6000），与该宏同步。

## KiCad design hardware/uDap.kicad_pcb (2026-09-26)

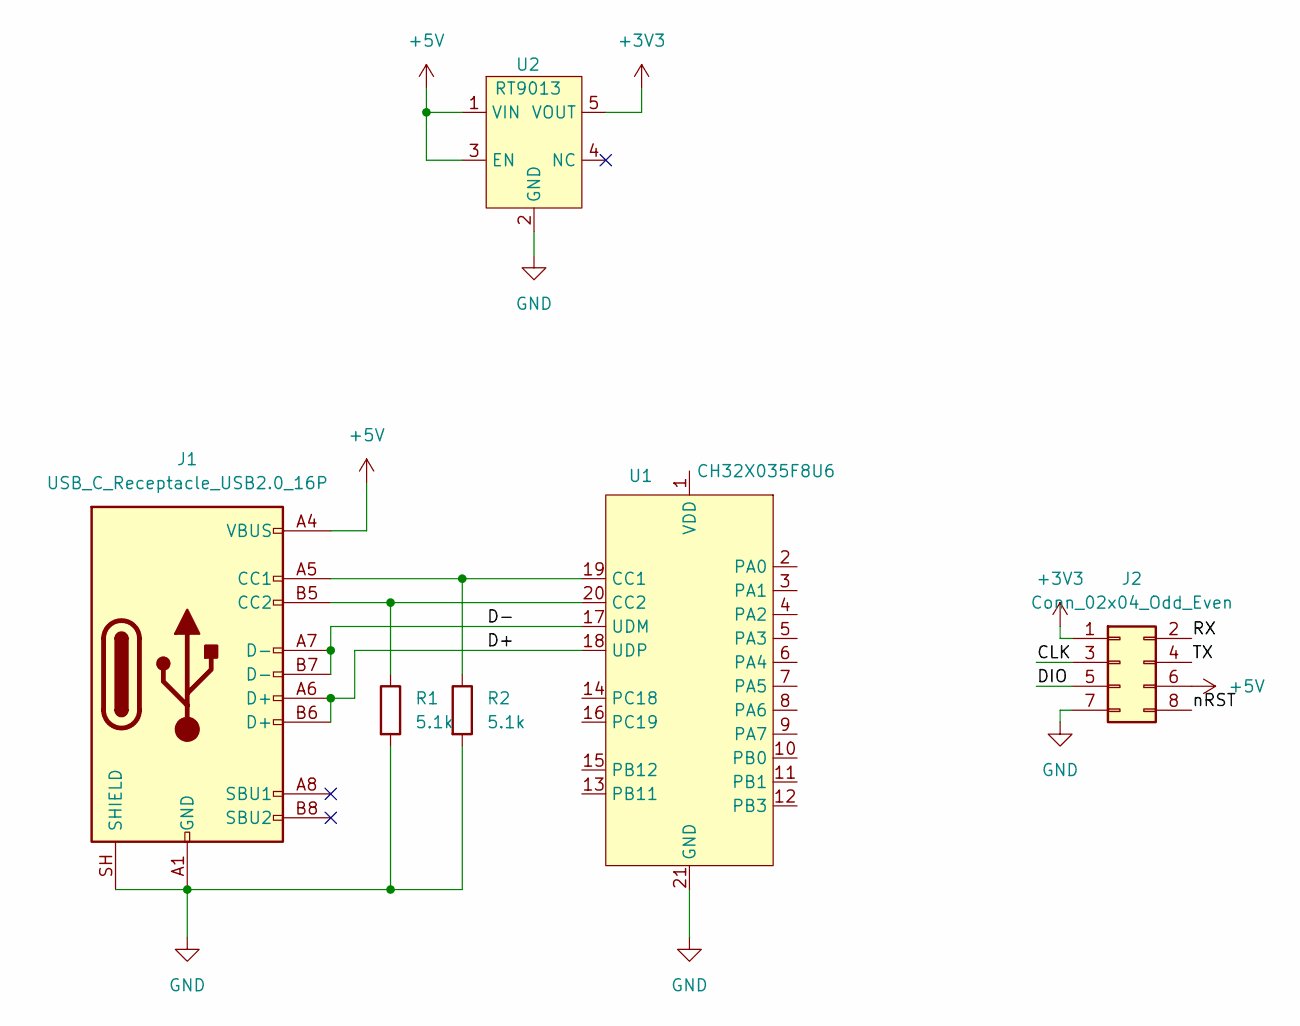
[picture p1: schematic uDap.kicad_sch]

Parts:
J1: USB_C_Receptacle_USB2.0_16P; USB_C_Receptacle_GCT_USB4105-xx-A_16P_TopMnt_Horizontal
J2: Conn_02x04_Odd_Even; PinHeader_2x04_P2.54mm_Vertical
R1, R2: 5.1k; R_0402_1005Metric
U1: CH32X035F8U6; QFN-20-1EP_3x3mm_P0.4mm_EP1.65x1.65mm
U2: RT9013; SOT-23-5

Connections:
+3V3: J2.1, U2.5 (VOUT)
+5V: J1.A4 (VBUS), J1.A9 (VBUS), J1.B4 (VBUS), J1.B9 (VBUS), J2.6, U2.1 (VIN), U2.3 (EN)
/CLK: J2.3
/D+: J1.A6 (D+), J1.B6 (D+), U1.18 (UDP)
/D-: J1.A7 (D-), J1.B7 (D-), U1.17 (UDM)
/DIO: J2.5
/RX: J2.2
/TX: J2.4
/nRST: J2.8
GND: J1.A1 (GND), J1.A12 (GND), J1.B1 (GND), J1.B12 (GND), J1.SH (SHIELD), J2.7, R1.2, R2.2, U1.21 (GND), U2.2 (GND)
unnamed: J1.A5 (CC1), R2.1, U1.19 (CC1)
unnamed: J1.B5 (CC2), R1.1, U1.20 (CC2)

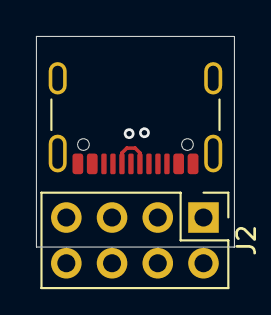
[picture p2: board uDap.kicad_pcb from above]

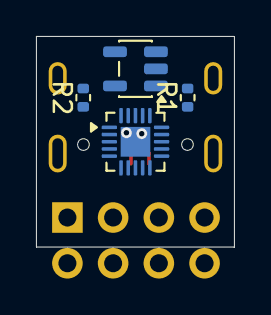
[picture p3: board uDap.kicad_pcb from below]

Board: 2 copper layers, 11.0 x 11.7 mm, 6 parts (4 on the bottom side), 7 nets.

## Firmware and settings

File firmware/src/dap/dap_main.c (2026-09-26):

#include "dap_main.h"

#include "drv/drv_uart.h"

// 序列号来源（xmake 的 option("esig_sn") -> -DESIG_SN=0/1）。
// 未定义时默认关闭：打开会改变 USB 序列号，进而改变主机侧的设备实例。
#ifndef ESIG_SN
#define ESIG_SN 0
#endif

#define CMSIS_DAP_INTERFACE_SIZE (9 + 7 + 7)
#define CUSTOM_HID_LEN           (9 + 9 + 7 + 7)

#define HIDRAW_INTERVAL 4

#define HID_CUSTOM_REPORT_DESC_SIZE 53

#define USBD_WINUSB_VENDOR_CODE 0x20
#define USBD_WEBUSB_VENDOR_CODE 0x21

#define USBD_WEBUSB_ENABLE 0
#define USBD_BULK_ENABLE   1
#define USBD_WINUSB_ENABLE 1

/* WinUSB Microsoft OS 2.0 descriptor sizes */
#define WINUSB_DESCRIPTOR_SET_HEADER_SIZE  10
#define WINUSB_FUNCTION_SUBSET_HEADER_SIZE 8
#define WINUSB_FEATURE_COMPATIBLE_ID_SIZE  20

#define FUNCTION_SUBSET_LEN                160
#define DEVICE_INTERFACE_GUIDS_FEATURE_LEN 132

#define USBD_WINUSB_DESC_SET_LEN (WINUSB_DESCRIPTOR_SET_HEADER_SIZE + USBD_WEBUSB_ENABLE * FUNCTION_SUBSET_LEN + USBD_BULK_ENABLE * FUNCTION_SUBSET_LEN)

#define USBD_NUM_DEV_CAPABILITIES (USBD_WEBUSB_ENABLE + USBD_WINUSB_ENABLE)

#define USBD_WEBUSB_DESC_LEN 24
#define USBD_WINUSB_DESC_LEN 28

#define USBD_BOS_WTOTALLENGTH (0x05 +                                      \
                               USBD_WEBUSB_DESC_LEN * USBD_WEBUSB_ENABLE + \
                               USBD_WINUSB_DESC_LEN * USBD_WINUSB_ENABLE)

#define USB_CONFIG_SIZE (9 + CMSIS_DAP_INTERFACE_SIZE + CDC_ACM_DESCRIPTOR_LEN + \
                         CONFIG_CHERRYDAP_USE_CUSTOM_HID * CUSTOM_HID_LEN +      \
                         CONFIG_CHERRYDAP_USE_MSC * MSC_DESCRIPTOR_LEN + USBD_WEBUSB_ENABLE * 9)

#define INTF_NUM (1 + 2 + CONFIG_CHERRYDAP_USE_CUSTOM_HID + CONFIG_CHERRYDAP_USE_MSC + USBD_WEBUSB_ENABLE)

#define MSC_INTF_NUM (3 + CONFIG_CHERRYDAP_USE_CUSTOM_HID)

#define WEBUSB_INTF_NUM (3 + CONFIG_CHERRYDAP_USE_CUSTOM_HID + CONFIG_CHERRYDAP_USE_MSC)

#define WEBUSB_URL_STRINGS \
    'c', 'h', 'e', 'r', 'r', 'y', 'd', 'a', 'p', '.', 'c', 'h', 'e', 'r', 'r', 'y', '-', 'e', 'm', 'b', 'e', 'd', 'd', 'e', 'd', '.', 'o', 'r', 'g',

__ALIGN_BEGIN const uint8_t USBD_WinUSBDescriptorSetDescriptor[] = {
    WBVAL(WINUSB_DESCRIPTOR_SET_HEADER_SIZE), /* wLength */
    WBVAL(WINUSB_SET_HEADER_DESCRIPTOR_TYPE), /* wDescriptorType */
    0x00, 0x00, 0x03, 0x06, /* >= Win 8.1 */  /* dwWindowsVersion*/
    WBVAL(USBD_WINUSB_DESC_SET_LEN),          /* wDescriptorSetTotalLength */
#if (USBD_WEBUSB_ENABLE)
    WBVAL(WINUSB_FUNCTION_SUBSET_HEADER_SIZE),  // wLength
    WBVAL(WINUSB_SUBSET_HEADER_FUNCTION_TYPE),  // wDescriptorType
    WEBUSB_INTF_NUM,                            // bFirstInterface USBD_WINUSB_IF_NUM
    0,                                          // bReserved
    WBVAL(FUNCTION_SUBSET_LEN),                 // wSubsetLength
    WBVAL(WINUSB_FEATURE_COMPATIBLE_ID_SIZE),   // wLength
    WBVAL(WINUSB_FEATURE_COMPATIBLE_ID_TYPE),   // wDescriptorType
    'W', 'I', 'N', 'U', 'S', 'B', 0, 0,         // CompatibleId
    0, 0, 0, 0, 0, 0, 0, 0,                     // SubCompatibleId
    WBVAL(DEVICE_INTERFACE_GUIDS_FEATURE_LEN),  // wLength
    WBVAL(WINUSB_FEATURE_REG_PROPERTY_TYPE),    // wDescriptorType
    WBVAL(WINUSB_PROP_DATA_TYPE_REG_MULTI_SZ),  // wPropertyDataType
    WBVAL(42),                                  // wPropertyNameLength
    'D', 0, 'e', 0, 'v', 0, 'i', 0, 'c', 0, 'e', 0,
    'I', 0, 'n', 0, 't', 0, 'e', 0, 'r', 0, 'f', 0, 'a', 0, 'c', 0, 'e', 0,
    'G', 0, 'U', 0, 'I', 0, 'D', 0, 's', 0, 0, 0,
    WBVAL(80),  // wPropertyDataLength
    '{', 0,
    '9', 0, '2', 0, 'C', 0, 'E', 0, '6', 0, '4', 0, '6', 0, '2', 0, '-', 0,
    '9', 0, 'C', 0, '7', 0, '7', 0, '-', 0,
    '4', 0, '6', 0, 'F', 0, 'E', 0, '-', 0,
    '9', 0, '3', 0, '3', 0, 'B', 0, '-',
    0, '3', 0, '1', 0, 'C', 0, 'B', 0, '9', 0, 'C', 0, '5', 0, 'A', 0, 'A', 0, '3', 0, 'B', 0, '9', 0,
    '}', 0, 0, 0, 0, 0,
#endif
#if USBD_BULK_ENABLE
    WBVAL(WINUSB_FUNCTION_SUBSET_HEADER_SIZE), /* wLength */
    WBVAL(WINUSB_SUBSET_HEADER_FUNCTION_TYPE), /* wDescriptorType */
    0,                                         /* bFirstInterface USBD_BULK_IF_NUM*/
    0,                                         /* bReserved */
    WBVAL(FUNCTION_SUBSET_LEN),                /* wSubsetLength */
    WBVAL(WINUSB_FEATURE_COMPATIBLE_ID_SIZE),  /* wLength */
    WBVAL(WINUSB_FEATURE_COMPATIBLE_ID_TYPE),  /* wDescriptorType */
    'W', 'I', 'N', 'U', 'S', 'B', 0, 0,        /* CompatibleId*/
    0, 0, 0, 0, 0, 0, 0, 0,                    /* SubCompatibleId*/
    WBVAL(DEVICE_INTERFACE_GUIDS_FEATURE_LEN), /* wLength */
    WBVAL(WINUSB_FEATURE_REG_PROPERTY_TYPE),   /* wDescriptorType */
    WBVAL(WINUSB_PROP_DATA_TYPE_REG_MULTI_SZ), /* wPropertyDataType */
    WBVAL(42),                                 /* wPropertyNameLength */
    'D', 0, 'e', 0, 'v', 0, 'i', 0, 'c', 0, 'e', 0,
    'I', 0, 'n', 0, 't', 0, 'e', 0, 'r', 0, 'f', 0, 'a', 0, 'c', 0, 'e', 0,
    'G', 0, 'U', 0, 'I', 0, 'D', 0, 's', 0, 0, 0,
    WBVAL(80), /* wPropertyDataLength */
    '{', 0,
    'C', 0, 'D', 0, 'B', 0, '3', 0, 'B', 0, '5', 0, 'A', 0, 'D', 0, '-', 0,
    '2', 0, '9', 0, '3', 0, 'B', 0, '-', 0,
    '4', 0, '6', 0, '6', 0, '3', 0, '-', 0,
    'A', 0, 'A', 0, '3', 0, '6', 0, '-',
    0, '1', 0, 'A', 0, 'A', 0, 'E', 0, '4', 0, '6', 0, '4', 0, '6', 0, '3', 0, '7', 0, '7', 0, '6', 0,
    '}', 0, 0, 0, 0, 0
#endif
};

__ALIGN_BEGIN const uint8_t USBD_BinaryObjectStoreDescriptor[] = {
    0x05,                         /* bLength */
    0x0f,                         /* bDescriptorType */
    WBVAL(USBD_BOS_WTOTALLENGTH), /* wTotalLength */
    USBD_NUM_DEV_CAPABILITIES,    /* bNumDeviceCaps */
#if (USBD_WEBUSB_ENABLE)
    USBD_WEBUSB_DESC_LEN,           /* bLength */
    0x10,                           /* bDescriptorType */
    USB_DEVICE_CAPABILITY_PLATFORM, /* bDevCapabilityType */
    0x00,                           /* bReserved */
    0x38,
    0xB6,
    0x08,
    0x34, /* PlatformCapabilityUUID */
    0xA9,
    0x09,
    0xA0,
    0x47,
    0x8B,
    0xFD,
    0xA0,
    0x76,
    0x88,
    0x15,
    0xB6,
    0x65,
    WBVAL(0x0100),
    /* 1.00 */               /* bcdVersion */
    USBD_WEBUSB_VENDOR_CODE, /* bVendorCode */
    1,                       /* iLandingPage */
#endif
#if (USBD_WINUSB_ENABLE)
    USBD_WINUSB_DESC_LEN,           /* bLength */
    0x10,                           /* bDescriptorType */
    USB_DEVICE_CAPABILITY_PLATFORM, /* bDevCapabilityType */
    0x00,                           /* bReserved */
    0xDF,
    0x60,
    0xDD,
    0xD8, /* PlatformCapabilityUUID */
    0x89,
    0x45,
    0xC7,
    0x4C,
    0x9C,
    0xD2,
    0x65,
    0x9D,
    0x9E,
    0x64,
    0x8A,
    0x9F,
    0x00,
    0x00,
    0x03,
    0x06,
    /* >= Win 8.1 */                 /* dwWindowsVersion*/
    WBVAL(USBD_WINUSB_DESC_SET_LEN), /* wDescriptorSetTotalLength */
    USBD_WINUSB_VENDOR_CODE,         /* bVendorCode */
    0,                               /* bAltEnumCode */
#endif
};

#define URL_DESCRIPTOR_LENGTH (3 + 29)

const uint8_t USBD_WebUSBURLDescriptor[URL_DESCRIPTOR_LENGTH] = {
    URL_DESCRIPTOR_LENGTH,
    WEBUSB_URL_TYPE,
    WEBUSB_URL_SCHEME_HTTPS,
    WEBUSB_URL_STRINGS};

// clang-format off
#define HID_DESC()                                                                                                                       \
    /************** Descriptor of Custom interface *****************/                                                                    \
    0x09,                                               /* bLength: Interface Descriptor size */                                         \
    USB_DESCRIPTOR_TYPE_INTERFACE,                  /* bDescriptorType: Interface descriptor type */                                 \
    0X03,                                           /* bInterfaceNumber: Number of Interface */                                      \
    0x00,                                           /* bAlternateSetting: Alternate setting */                                       \
    0x02,                                           /* bNumEndpoints */                                                              \
    0x03,                                           /* bInterfaceClass: HID */                                                       \
    0x01,                                           /* bInterfaceSubClass : 1=BOOT, 0=no boot */                                     \
    0x00,                                           /* nInterfaceProtocol : 0=none, 1=keyboard, 2=mouse */                           \
    0, /* iInterface: Index of string descriptor */ /******************** Descriptor of Custom HID ********************/             \
    0x09,                                           /* bLength: HID Descriptor size */                                               \
    HID_DESCRIPTOR_TYPE_HID,                        /* bDescriptorType: HID */                                                       \
    0x11,                                           /* bcdHID: HID Class Spec release number */                                      \
    0x01,                                                                                                                            \
    0x00,                                              /* bCountryCode: Hardware target country */                                   \
    0x01,                                              /* bNumDescriptors: Number of HID class descriptors to follow */              \
    0x22,                                              /* bDescriptorType */                                                         \
    HID_CUSTOM_REPORT_DESC_SIZE,                       /* wItemLength: Total length of Report descriptor */                          \
    0x00,                                              /******************** Descriptor of Custom in endpoint ********************/  \
    0x07,                                              /* bLength: Endpoint Descriptor size */                                       \
    USB_DESCRIPTOR_TYPE_ENDPOINT,                      /* bDescriptorType: */                                                        \
    HID_IN_EP,                                         /* bEndpointAddress: Endpoint Address (IN) */                                 \
    0x03,                                              /* bmAttributes: Interrupt endpoint */                                        \
    WBVAL(HID_PACKET_SIZE),                            /* wMaxPacketSize: 4 Byte max */                                              \
    HIDRAW_INTERVAL, /* bInterval: Polling Interval */ /******************** Descriptor of Custom out endpoint ********************/ \
    0x07,                                              /* bLength: Endpoint Descriptor size */                                       \
    USB_DESCRIPTOR_TYPE_ENDPOINT,                      /* bDescriptorType: */                                                        \
    HID_OUT_EP,                                        /* bEndpointAddress: Endpoint Address (IN) */                                 \
    0x03,                                              /* bmAttributes: Interrupt endpoint */                                        \
    WBVAL(HID_PACKET_SIZE),                            /* wMaxPacketSize: 4 Byte max */                                              \
    HIDRAW_INTERVAL                                    /* bInterval: Polling Interval */
// clang-format on

static const uint8_t device_descriptor[] = {
    USB_DEVICE_DESCRIPTOR_INIT(USB_2_1, 0xEF, 0x02, 0x01, USBD_VID, USBD_PID, 0x0100, 0x01),
};

static const uint8_t config_descriptor[] = {
    USB_CONFIG_DESCRIPTOR_INIT(USB_CONFIG_SIZE, INTF_NUM, 0x01, USB_CONFIG_BUS_POWERED, USBD_MAX_POWER),
    /* Interface 0 */
    USB_INTERFACE_DESCRIPTOR_INIT(0x00, 0x00, 0x02, 0xFF, 0x00, 0x00, 0x02),
    /* Endpoint OUT 2 */
    USB_ENDPOINT_DESCRIPTOR_INIT(DAP_OUT_EP, USB_ENDPOINT_TYPE_BULK, DAP_PACKET_SIZE, 0x00),
    /* Endpoint IN 1 */
    USB_ENDPOINT_DESCRIPTOR_INIT(DAP_IN_EP, USB_ENDPOINT_TYPE_BULK, DAP_PACKET_SIZE, 0x00),
    CDC_ACM_DESCRIPTOR_INIT(0x01, CDC_INT_EP, CDC_OUT_EP, CDC_IN_EP, DAP_PACKET_SIZE, 0x00),
#if CONFIG_CHERRYDAP_USE_CUSTOM_HID
    HID_DESC(),
#endif
#if CONFIG_CHERRYDAP_USE_MSC
    MSC_DESCRIPTOR_INIT(MSC_INTF_NUM, MSC_OUT_EP, MSC_IN_EP, DAP_PACKET_SIZE, 0x00),
#endif
#if USBD_WEBUSB_ENABLE
    USB_INTERFACE_DESCRIPTOR_INIT(WEBUSB_INTF_NUM, 0x00, 0x00, 0xff, 0x00, 0x00, 0x04),
#endif
};

static const uint8_t other_speed_config_descriptor[] = {
    USB_CONFIG_DESCRIPTOR_INIT(USB_CONFIG_SIZE, INTF_NUM, 0x01, USB_CONFIG_BUS_POWERED, USBD_MAX_POWER),
    /* Interface 0 */
    USB_INTERFACE_DESCRIPTOR_INIT(0x00, 0x00, 0x02, 0xFF, 0x00, 0x00, 0x02),
    /* Endpoint OUT 2 */
    USB_ENDPOINT_DESCRIPTOR_INIT(DAP_OUT_EP, USB_ENDPOINT_TYPE_BULK, DAP_PACKET_SIZE, 0x00),
    /* Endpoint IN 1 */
    USB_ENDPOINT_DESCRIPTOR_INIT(DAP_IN_EP, USB_ENDPOINT_TYPE_BULK, DAP_PACKET_SIZE, 0x00),
    CDC_ACM_DESCRIPTOR_INIT(0x01, CDC_INT_EP, CDC_OUT_EP, CDC_IN_EP, DAP_PACKET_SIZE, 0x00),
#if CONFIG_CHERRYDAP_USE_CUSTOM_HID
    HID_DESC(),
#endif
#if CONFIG_CHERRYDAP_USE_MSC
    MSC_DESCRIPTOR_INIT(0x04, MSC_OUT_EP, MSC_IN_EP, DAP_PACKET_SIZE, 0x00),
#endif
#if USBD_WEBUSB_ENABLE
    USB_INTERFACE_DESCRIPTOR_INIT(WEBUSB_INTF_NUM, 0x00, 0x00, 0xff, 0x00, 0x00, 0x04),
#endif
};

/*!< custom hid report descriptor */
const uint8_t hid_custom_report_desc[HID_CUSTOM_REPORT_DESC_SIZE] = {
    /* USER CODE BEGIN 0 */
    0x06, 0x00, 0xff, /* USAGE_PAGE (Vendor Defined Page 1) */
    0x09, 0x01,       /* USAGE (Vendor Usage 1) */
    0xa1, 0x01,       /* COLLECTION (Application) */
    0x85, 0x02,       /*   REPORT ID (0x02) */
    0x09, 0x02,       /*   USAGE (Vendor Usage 1) */
    0x15, 0x00,       /*   LOGICAL_MINIMUM (0) */
    0x25, 0xff,       /*LOGICAL_MAXIMUM (255) */
    0x75, 0x08,       /*   REPORT_SIZE (8) */
    0x96, 0xff, 0x03, /*   REPORT_COUNT (1023) */
    0x81, 0x02,       /*   INPUT (Data,Var,Abs) */
    /* <___________________________________________________> */
    0x85, 0x01,       /*   REPORT ID (0x01) */
    0x09, 0x03,       /*   USAGE (Vendor Usage 1) */
    0x15, 0x00,       /*   LOGICAL_MINIMUM (0) */
    0x25, 0xff,       /*   LOGICAL_MAXIMUM (255) */
    0x75, 0x08,       /*   REPORT_SIZE (8) */
    0x96, 0xff, 0x03, /*   REPORT_COUNT (1023) */
    0x91, 0x02,       /*   OUTPUT (Data,Var,Abs) */

    /* <___________________________________________________> */
    0x85, 0x03,       /*   REPORT ID (0x03) */
    0x09, 0x04,       /*   USAGE (Vendor Usage 1) */
    0x15, 0x00,       /*   LOGICAL_MINIMUM (0) */
    0x25, 0xff,       /*   LOGICAL_MAXIMUM (255) */
    0x75, 0x08,       /*   REPORT_SIZE (8) */
    0x96, 0xff, 0x03, /*   REPORT_COUNT (1023) */
    0xb1, 0x02,       /*   FEATURE (Data,Var,Abs) */
    /* USER CODE END 0 */
    0xC0 /*     END_COLLECTION	             */
};

// USB 序列号。默认是固定的 "DEADBEEF"；打开 ESIG_SN 时会被芯片出厂 UID 覆盖。
// 36 字节足够放 24 个 UID 十六进制字符（+ 结束符）。
char serial_number_dynamic[36] = "DEADBEEF";

#if ESIG_SN
// ---------------------------------------------------------------------------
// 序列号改用芯片出厂 UID（ESIG，Electronic Signature）
// ---------------------------------------------------------------------------
// 默认的固定串对所有板子都一样，多块插在同一台机器上无法区分（VID:PID 也相同）。
// ESIG 区的 96 位 UID 出厂烧录、只读、对每颗芯片唯一，适合做产品序列号。
// 寄存器定义见 CH32X035 应用手册第 19 章「电子签名（ESIG）」：
//   0x1FFFF7E8  R32_ESIG_UNIID1  U_ID[31:0]
//   0x1FFFF7EC  R32_ESIG_UNIID2  U_ID[63:32]
//   0x1FFFF7F0  R32_ESIG_UNIID3  U_ID[95:64]
//
// 注意：USB 序列号参与主机侧的设备枚举与驱动匹配，换了序列号等于换了设备实例，
// 首次插入需要重新匹配一次驱动（本设备是 WinUSB，靠 MS OS 2.0 描述符自动匹配，
// 无需手工安装）。这是预期行为，不是故障。
#define ESIG_UNIID1_ADDR 0x1FFFF7E8u /* U_ID[31:0]  */
#define ESIG_UNIID2_ADDR 0x1FFFF7ECu /* U_ID[63:32] */
#define ESIG_UNIID3_ADDR 0x1FFFF7F0u /* U_ID[95:64] */
#define ESIG_SN_HEX_LEN  24u         /* 96 位 -> 24 个十六进制字符 */

// 一个 32 位字 -> 8 个大写十六进制字符（高位在前）
static void esig_sn_put_word(uint32_t value, char *out) {
    static const char hex[] = "0123456789ABCDEF";

    for (uint32_t i = 0u; i < 8u; i++) {
        out[i] = hex[(value >> (28u - 4u * i)) & 0x0Fu];
    }
}

// 检查刚拼好的 UID 串是否「像个有效值」（不全 0、不全 F）
static bool esig_sn_uid_is_plausible(void) {
    bool all_zero = true;
    bool all_ff = true;

    for (uint32_t i = 0u; i < ESIG_SN_HEX_LEN; i++) {
        if (serial_number_dynamic[i] != '0') {
            all_zero = false;
        }
        if (serial_number_dynamic[i] != 'F') {
            all_ff = false;
        }
    }
    return !(all_zero || all_ff);
}

// 按 UNIID1 -> UNIID2 -> UNIID3 拼接（与沁恒例程的打印顺序一致；顺序只是约定，
// 唯一性不受影响）。三个地址逐个显式读取（虽然是相邻的 +0/+4/+8），这样每个
// 地址都能在自己那一行独立对照手册，不必依赖「它们相邻」这个隐含前提。
static void esig_sn_apply(void) {
    static const char fallback[] = "DEADBEEF";

    esig_sn_put_word(*(const volatile uint32_t *)ESIG_UNIID1_ADDR,
                     &serial_number_dynamic[0]);
    esig_sn_put_word(*(const volatile uint32_t *)ESIG_UNIID2_ADDR,
                     &serial_number_dynamic[8]);
    esig_sn_put_word(*(const volatile uint32_t *)ESIG_UNIID3_ADDR,
                     &serial_number_dynamic[16]);
    serial_number_dynamic[ESIG_SN_HEX_LEN] = '\0';

    // 全 0 或全 FF 表示没读到有效 UID（地址不对、ESIG 不可读、总线返回未初始化值）。
    // 这时**退回固定串**，而不是把一个「看似唯一、其实所有板子都一样」的串当成
    // 序列号发出去 —— 后者会让本特性悄无声息地失效，且主机侧无从察觉。
    // （本工程 _write 是空实现，没法打印告警，所以只能靠退回固定串让现象可见。）
    if (!esig_sn_uid_is_plausible()) {
        for (uint32_t i = 0u; i < sizeof(fallback); i++) {
            serial_number_dynamic[i] = fallback[i];
        }
    }
}
#endif /* ESIG_SN */

// 供 DAP_config.h 的 DAP_GetSerNumString() 取用（CMSIS-DAP 的 DAP_GetSerNum 命令）。
// 与 USB 描述符的 iSerialNumber 用同一份字符串，保证两条路径报告一致。
const char *udap_serial_number(void) {
    return serial_number_dynamic;
}

char *string_descriptors[] = {
    (char[]){0x09, 0x04},  /* Langid */
    "uDAP",                /* Manufacturer */
    "uDAP CMSIS-DAP",      /* Product */
    serial_number_dynamic, /* Serial Number（固定值或 ESIG UID） */
    "uDAP WebUSB",
};

static const uint8_t device_quality_descriptor[] = {
    USB_DEVICE_QUALIFIER_DESCRIPTOR_INIT(USB_2_1, 0x00, 0x00, 0x00, 0x01),
};

__WEAK const uint8_t *device_descriptor_callback(uint8_t speed) {
    (void)speed;
    return device_descriptor;
}

__WEAK const uint8_t *config_descriptor_callback(uint8_t speed) {
    (void)speed;
    return config_descriptor;
}

__WEAK const uint8_t *device_quality_descriptor_callback(uint8_t speed) {
    (void)speed;
    return device_quality_descriptor;
}

__WEAK const uint8_t *other_speed_config_descriptor_callback(uint8_t speed) {
    (void)speed;
    return other_speed_config_descriptor;
}

__WEAK const char *string_descriptor_callback(uint8_t speed, uint8_t index) {
    (void)speed;

    // 序列号（index 3）也在 string_descriptors 里，指向 serial_number_dynamic，
    // 所以这里不需要再特判
    if (index >= (sizeof(string_descriptors) / sizeof(char *))) {
        return NULL;
    }
    return string_descriptors[index];
}

static volatile uint16_t USB_RequestIndexI = 0;  // Request  Index In
static volatile uint16_t USB_RequestIndexO = 0;  // Request  Index Out
static volatile uint16_t USB_RequestCountI = 0;  // Request  Count In
static volatile uint16_t USB_RequestCountO = 0;  // Request  Count Out
static volatile uint8_t USB_RequestIdle = 1;     // Request  Idle  Flag

static volatile uint16_t USB_ResponseIndexI = 0;  // Response Index In
static volatile uint16_t USB_ResponseIndexO = 0;  // Response Index Out
static volatile uint16_t USB_ResponseCountI = 0;  // Response Count In
static volatile uint16_t USB_ResponseCountO = 0;  // Response Count Out
static volatile uint8_t USB_ResponseIdle = 1;     // Response Idle  Flag

static USB_NOCACHE_RAM_SECTION USB_MEM_ALIGNX uint8_t USB_Request[DAP_PACKET_COUNT][DAP_PACKET_SIZE];   // Request  Buffer
static USB_NOCACHE_RAM_SECTION USB_MEM_ALIGNX uint8_t USB_Response[DAP_PACKET_COUNT][DAP_PACKET_SIZE];  // Response Buffer
static uint16_t USB_RespSize[DAP_PACKET_COUNT];                                                         // Response Size

// COM 口现在是 USART4 (PB0=TX, PB1=RX) 的双向桥。
//
// 两个方向的缓冲大小取值不同，原因在 USB 端口层的完成判据
// （x035_usb_complete_noncontrol_out）：
//     complete = packet_len < mps || remaining == 0 || copy_len != packet_len
// 即 OUT 方向只有「收满请求长度」或「收到短包」才算完成。而 USB CDC 批量 OUT
// 没有长度字段，主机写 64 字节（正好等于端点 MPS）时既不是短包、也填不满更长的
// 请求长度，端点就会一直等下去 —— 回调不触发、数据不回环。
// 所以 OUT 的请求长度**必须**等于 MPS：这样每个包都让 remaining 归零立即完成，
// 任意主机写长度都会自然拆成 64 + 余数（余数 < MPS 同样是短包）。
//
// IN 方向相反，长度由设备决定，可以一次带多个包，所以用大缓冲减少 USB 往返。
#define CDC_OUT_BUFFER_SIZE DAP_PACKET_SIZE
#define CDC_IN_BUFFER_SIZE  512u

static USB_NOCACHE_RAM_SECTION USB_MEM_ALIGNX uint8_t cdc_out_buffer[CDC_OUT_BUFFER_SIZE];
static USB_NOCACHE_RAM_SECTION USB_MEM_ALIGNX uint8_t cdc_in_buffer[CDC_IN_BUFFER_SIZE];
static volatile struct cdc_line_coding g_cdc_lincoding;
static volatile uint8_t cdc_tx_busy;

// CDC OUT 背压标志：UART TX FIFO 余量不足时置位，表示 OUT 端点已停止重挂。
// 排空到能再容一整包后，由 chry_dap_cdc_bridge() 重新挂起。
static volatile uint8_t cdc_out_stalled;
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

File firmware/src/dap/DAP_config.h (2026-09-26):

#pragma once

#include <stdint.h>

#include <ch32x035.h>

#ifndef __STATIC_INLINE
#define __STATIC_INLINE static inline
#endif
#ifndef __STATIC_FORCEINLINE
#define __STATIC_FORCEINLINE __attribute__((always_inline)) static inline
#endif
#ifndef __WEAK
#define __WEAK __attribute__((weak))
#endif

#define CPU_CLOCK               48000000U
#define IO_PORT_WRITE_CYCLES    2U

// 快路径（SWD_TransferFast）的启用阈值。
//
// 判定点在 cherrydap 的 Set_Clock_Delay()（DAP/Source/DAP.c，__WEAK）：
//     if (clock >= MAX_SWJ_CLOCK(DELAY_FAST_CYCLES)) -> fast_clock = 1
//     MAX_SWJ_CLOCK(n) = (CPU_CLOCK / 2) / (IO_PORT_WRITE_CYCLES + n)
// 代入本文件的值与下面的 DELAY_FAST_CYCLES = 2U：
//     (48 MHz / 2) / (2 + 2) = 6 MHz
// 即**请求时钟 >= 6 MHz 就走快路径**（上游默认 DELAY_FAST_CYCLES = 0，阈值 12 MHz）。
//
// 为什么降到 6 MHz：快路径的实际 SWCLK 由固定指令数决定（约 6 MHz），
// **与请求值无关** —— 请求 6 MHz 与请求 12 MHz 拿到的是同一个速率。阈值留在
// 12 MHz 的唯一后果，是让主机填 6 ~ 11.5 MHz 时白跑慢路径（实测慢路径 56 KiB/s
// vs 快路径 129 KiB/s，见仓库根 readme.md 第 6.1 节）。6 MHz 以下仍走慢路径，
// 保留可调延时，供长线 / 慢目标使用。
//
// 改阈值只需改这个数（阈值 = 24 MHz / (2 + 本值)）：
//     0 -> 12 MHz（上游默认）    2 -> 6 MHz（本工程）    4 -> 4 MHz
//
// ⚠️ DELAY_FAST_CYCLES 在 DAP.h 里还有一个用途：决定 PIN_DELAY_FAST() 补几个 NOP。
// 在本工程里**不影响时序** —— sw_dp.c 已把 PIN_DELAY_FAST 重定义成固定一个
// __NOP()，且上游唯二使用它的 SW_DP.c / JTAG_DP.c 并未参与编译（见 xmake.lua）。
// 也就是说这个宏在本工程里只当阈值旋钮用。
#ifndef DELAY_FAST_CYCLES
#define DELAY_FAST_CYCLES 2U
#endif

// 慢路径（SWD_TransferSlow）的单次位延时
//
#ifndef DELAY_SLOW_CYCLES
#define DELAY_SLOW_CYCLES 8U
#endif

__STATIC_FORCEINLINE void x035_pin_delay_slow(uint32_t delay) {
  uint32_t count = delay;
  while (--count) {
    __NOP();
  }
}


#define DAP_SWD                 1
#define DAP_JTAG                0
#define DAP_JTAG_DEV_CNT        1U
#define DAP_DEFAULT_PORT        1U
#define DAP_DEFAULT_SWJ_CLOCK   1000000U
#define DAP_PACKET_SIZE         64U
#define DAP_PACKET_COUNT        8U
#define SWO_UART                0
#define SWO_MANCHESTER          0
#define SWO_STREAM              0
#define SWO_BUFFER_SIZE         256U
#define TIMESTAMP_CLOCK         0U
#define DAP_UART                0
#define DAP_UART_USB_COM_PORT   1
#define DAP_UART_DRIVER         0
#define DAP_UART_RX_BUFFER_SIZE 64U
#define DAP_UART_TX_BUFFER_SIZE 64U
#define DAP_FW_VER              "0.1.0"

__STATIC_INLINE uint8_t DAP_GetVendorString(char *str) {
    (void)str;
    return 0U;
}
__STATIC_INLINE uint8_t DAP_GetProductString(char *str) {
    (void)str;
    return 0U;
}

// 序列号由 src/dap/dap_main.c 提供：USB 描述符的 iSerialNumber 与这里的
// DAP_GetSerNum 命令共用同一份字符串，避免两条路径报告不同的序列号
// （后者只在主机主动查询 DAP_ID_SER_NUM 时才用到，如 pyOCD 的探针列表）。
//
// 声明放在本文件而不是 dap_main.h：dap_main.h 会 include 本文件，反向包含会成环。
extern const char *udap_serial_number(void);

// 返回写入的字符数（不含结束符）。CMSIS-DAP 规定字符串最长 32 字符，
// 而 DAP_Info 的响应缓冲就是 DAP_PACKET_SIZE(64)，所以 32 是安全上限。
__STATIC_INLINE uint8_t DAP_GetSerNumString(char *str) {
    const char *sn = udap_serial_number();
    uint8_t n = 0U;

    if (sn != NULL) {
        while (sn[n] != '\0' && n < 32U) {
            str[n] = sn[n];
            n++;
        }
    }
    return n;
}

__STATIC_INLINE uint8_t DAP_GetTargetDeviceVendorString(char *str) {
    (void)str;
    return 0U;
}
__STATIC_INLINE uint8_t DAP_GetTargetDeviceNameString(char *str) {
    (void)str;
    return 0U;
}
__STATIC_INLINE uint8_t DAP_GetTargetBoardVendorString(char *str) {
    (void)str;
    return 0U;
}
__STATIC_INLINE uint8_t DAP_GetTargetBoardNameString(char *str) {
    (void)str;
    return 0U;
}
__STATIC_INLINE uint8_t DAP_GetProductFirmwareVersionString(char *str) {
    (void)str;
    return 0U;
}

// PA2 为 SWCLK，PA3 为 SWDIO，PA5 为 nRESET（低有效）
// BSHR 低 16 位将输出置高，BCR 将输出拉低
__STATIC_FORCEINLINE uint32_t PIN_SWCLK_TCK_IN(void) { return (GPIOA->INDR & GPIO_Pin_2) != 0U; }
__STATIC_FORCEINLINE void PIN_SWCLK_TCK_SET(void) { GPIOA->BSHR = GPIO_Pin_2; }
__STATIC_FORCEINLINE void PIN_SWCLK_TCK_CLR(void) { GPIOA->BCR = GPIO_Pin_2; }
__STATIC_FORCEINLINE uint32_t PIN_SWDIO_TMS_IN(void) { return (GPIOA->INDR & GPIO_Pin_3) != 0U; }
__STATIC_FORCEINLINE void PIN_SWDIO_TMS_SET(void) { GPIOA->BSHR = GPIO_Pin_3; }
__STATIC_FORCEINLINE void PIN_SWDIO_TMS_CLR(void) { GPIOA->BCR = GPIO_Pin_3; }
#define PIN_SWDIO_IN() ((GPIOA->INDR & GPIO_Pin_3) != 0U)
// 在 BSHR 的置位与复位半字间选择，避免每个数据位都执行条件分支
#define PIN_SWDIO_OUT(bit) {GPIOA->BSHR = (GPIO_Pin_3 << 16) >> ((bit & 1U) << 4);}
// 设置 SWDIO 数据，并将 SWCLK 原子拉低，为下一个 SWD 数据位准备
__STATIC_FORCEINLINE void PIN_SWDIO_OUT_SWCLK_CLR(uint32_t bit) {
    // 同时设置 PA3 数据并拉低 PA2，bit 为 0 时选择 BSHR 的复位半字
    GPIOA->BSHR = ((GPIO_Pin_3 << 16) >> ((bit & 1U) << 4));
}
// CFGLR 为 PA0 至 PA7 每个引脚分配 4 位，0x1 为推挽输出，0x4 为浮空输入
__STATIC_FORCEINLINE void PIN_SWDIO_OUT_ENABLE(void) {
    // PA3 的 12 至 15 位，从浮空输入切换为推挽输出
    GPIOA->CFGLR = (GPIOA->CFGLR & ~(0xFU << 12)) | (0x1U << 12);
}
__STATIC_FORCEINLINE void PIN_SWDIO_OUT_DISABLE(void) {
    // PA3 的 12 至 15 位，释放 SWDIO 供目标驱动
    GPIOA->CFGLR = (GPIOA->CFGLR & ~(0xFU << 12)) | (0x4U << 12);
}
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

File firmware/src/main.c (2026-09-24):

#include "bsp/bsp_delay.h"
#include "bsp/bsp_system.h"

#include <ch32x035.h>

// CMSIS-DAP 是可选功能，由 xmake.lua 的 dap 选项控制：
//   xmake f --dap=n   # 关闭，只保留 USB 骨架
// 未定义时默认启用，便于 MRS 等不传该宏的构建方式。
#ifndef ENABLE_DAP
#define ENABLE_DAP 1
#endif

#if ENABLE_DAP
#include "dap_main.h"
#include "drv/drv_uart.h"

static void __attribute__((section(".highcode"), noinline, optimize("O2"))) cherrydap_process(void) {

    for (;;) {
        chry_dap_handle();
        chry_dap_cdc_bridge();
    }
}
#endif

int main(void) {
    SystemInit();
    bsp_delay_init();
    NVIC_PriorityGroupConfig(NVIC_PriorityGroup_1);

    bsp_delay_ms(10u);

#if ENABLE_DAP
    // COM 口 <-> USART4 (PB0=TX, PB1=RX)，默认 115200；
    // 主机改 CDC 行编码时波特率会跟着变
    drv_uart_init(0u);

    chry_dap_init(0u, 0u);

    cherrydap_process();
#else
    for (;;) {
        bsp_delay_ms(1000u);
    }
#endif
}

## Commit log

2026-09-24 feat: 添加 CH32X035F8U CMSIS-DAP 调试器固件（uDap2）
    基于 CherryUSB + CherryDAP，xmake + WCH RISC-V GCC 构建，工程根为 firmware/。
    USB（必选）
    - CherryUSB 核心 + CDC ACM 类；CH32X035 USBFS 设备端口 glue 在 src/port/
    - src/bsp/bsp_usb.c 补齐芯片级 USB 硬件初始化：CherryUSB 端口层把
    usb_dc_low_level_init 声明为 __WEAK，时钟 / PC16 / PC17 / AFIO PHY / NVIC
    必须由应用侧提供；按供电电压选择 PHY 配置（5V 关 PHY_V33 且 10K 上拉，
    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
2026-09-26 fix(cdc): COM 口 TX 侧加背压，并把波特率上限定在 2 Mbaud
    主机向 COM 口 bulk 写入时不再无条件重挂 OUT 端点：只有 UART TX FIFO 除本包
    外还能再容一整包（CDC_OUT_BUFFER_SIZE）时才重挂，否则置背压标志、让主机一直
    收到 NAK，其 write() 自然阻塞在串口波特率上，从而做到零丢字节。旧行为下 USB
    会以 MB/s 级速度灌满 FIFO，超出部分直接丢弃（实测 115200 下写 8192 B 丢 85%），
    与主机等长回读的脚本表现为「一直跑不结束」。
    - drv_uart: 新增 drv_uart_tx_free()，作为 USB 侧判断余量的依据
    - dap_main: chry_dap_cdc_bridge() 改为同时推进两个方向；OUT 背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
    [dap_main.c, drv_uart.c]
2026-09-26 perf: SWD 快路径阈值降到 6 MHz、撤除 COM 口波特率上限，补齐测速工具与性能文档
    ## 固件行为变更
    1) SWD 快路径启用阈值 12 MHz -> 6 MHz（src/dap/DAP_config.h）
    阈值不是硬编码常量，而是 CherryDAP 的 Set_Clock_Delay() 用
    MAX_SWJ_CLOCK(DELAY_FAST_CYCLES) = (CPU_CLOCK/2)/(IO_PORT_WRITE_CYCLES + n)
    算出来的；上游默认 n=0 即 12 MHz。本工程令 DELAY_FAST_CYCLES = 2 ->
    (48M/2)/(2+2) = 6 MHz。
    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
    [com_loopback.csv, com_loopback_highbaud.csv, swd_sweep_16k.csv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]
2026-09-26 feat(dap): 新增 esig_sn 选项，可用芯片出厂 UID 作 USB 序列号
    默认所有板子的序列号都是固定的 "DEADBEEF"，而本设备 VID:PID 也是固定的
    0d28:0204，所以多块板子同时插在一台机器上时主机无法区分。新增编译选项
    esig_sn（build.ps1 的 -EsigSn y）打开后，改用芯片 ESIG 区的 96 位出厂 UID
    作序列号 —— 出厂烧录、只读、每颗芯片唯一。
    ## 选项
    .\build.ps1 -EsigSn y
    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
2026-09-26 feat: 新增 .gitattributes 文件以自动处理文本文件的换行符。添加硬件设计文件
    [uDap.kicad_pcb, uDap.kicad_sch]
2026-10-04 refactor: 抽出芯片 UID / CDC 行编码 / 段属性宏等公共层，为双模式固件做准备
    - bsp/bsp_uid.{c,h}：新增芯片 UID 读取（DBGMCU_GetCHIPID + CHIP_UID_1/2）与 16 进制
    串转换，供 esig_sn 与后续 WCH-Link 的 ESIG 共用。
    - drv/drv_cdc_line.{c,h}：把 usbd_cdc_acm_* 行编码回调从 dap/dap_main.c 收敛成一份。
    原先 CMSIS-DAP 与 WCH-Link 各写一份会导致双模式固件重复符号、链接失败；合并后行为
    不变（存行编码 + 把 dwDTERate 下发给 drv_uart，无上限检查），默认 115200 8N1 与
    drv_uart 默认波特率一致，DTR/RTS 仍为空实现。
    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
2026-10-04 feat(wchlink): 新增 WCH-Link（RVSWD）调试/烧录模式，并支持与 CMSIS-DAP 同固件运行期切换
    WCH-Link 模式（--dap=n --wchlink=y）
    - src/wchlink/：移植 ch32x035-usb-wchlink-main 的实现，按 protocol / transport / rvswd /
    target / flash / session / usb 分层，覆盖 CH32X03X、CH32L10X、CH32V20X、CH32V30X、
    CH58X、CH59X 六个目标族的连接、读写、擦除、下载与校验。
    - 相对来源工程的适配：CDC 由回环改为与 CMSIS-DAP 一致的 USART4（PB0/PB1）双向桥，含 TX
    背压、波特率跟随主机 SET_LINE_CODING；序列号改用 bsp_get_uid_hex16()；状态灯与目标电源
    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
2026-10-04 修复了串口波特率计算过于复杂的问题
2026-10-04 feat(mode): 取消单模式构建，并用用户选择字 Data0 持久化当前模式
    取消单模式构建（--dap / --wchlink）
    - xmake.lua：删掉 option("dap") / option("wchlink") 与 ENABLE_DAP / ENABLE_WCHLINK 宏，
    两套调试器代码强制同时编入，链接脚本固定为 Link_highcode_nv_256B_dual.ld。
    - build.ps1：删掉 -Dap / -Wchlink 参数与 esig_sn 对 DAP 的依赖校验（固件恒含 CMSIS-DAP）。
    - src/main.c、src/mode_overlay.h：去掉 ENABLE_DUAL_MODE / ENABLE_CDC_BRIDGE 等条件分支，
    段属性宏不再退化成 .highcode，overlay 初始化也不再提供单模式空实现。
    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
2026-10-11 perf(dap): SWD 逐位时序改用内联汇编钉住，overlay 只保留数据
    SWD 逐位时序（src/dap/sw_dp.c、src/dap/DAP_config.h）
    - 为什么必须换汇编：C 版钉不住逐位顺序 —— GCC 总把「算下一位 BSHR 值」的 ALU
    提到下降沿那条 store 之前（它总是尽早算值以隐藏 MMIO 退休延迟），实测低电平期
    只剩 1 条 store（约 20 ns）、高电平期塞进 5 条 ALU（约 140 ns），占空比 1:7。
    试过 __attribute__((optimize("O2","no-schedule-insns","no-schedule-insns2")))，
    反汇编一字未变 —— 重排来自 GCC「算值尽早」的通用策略，不是调度器 pass，
    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
2026-10-12 perf(dap): 读数据相位改用内联汇编（每 bit 8 clk、低 4/高 4），并新增 pyocd 测速工具
    读数据相位（src/dap/sw_dp.c）
    - 原文是 C 循环 + SWD_FAST_READ_LOW / SWD_FAST_READ_HIGH / SWD_FAST_PACK_BARRIER
    三个宏：每 bit 拉低 -> 采样 INDR -> 拉高，每收 4 位攒进 packed，再
    `val >>= 4; val |= (packed << 28)`。GCC 生成每 bit 要 10~11 个 clk ——
    PIN_SWCLK_SET_READ() 自带 3 个 nop、外层再加 PIN_DELAY_FAST() 1 个，高电平期
    被补到 5 个 clk，而低电平期还要再塞进采样与位打包。
    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
2026-10-12 docs: 把 4 份文档合并进根 readme.md，并更新尺寸/序列号/性能数据
    合并目标与来源
    - 根 readme.md 变成**唯一的项目文档**（607 -> 2013 行 / 105 KB），
    以下 4 份的正文按原文（逐字节）搬运，只重写标题编号与交叉引用：
    firmware/README.md 686 行 固件内部细节
    firmware/docs/architecture.md 448 行 代码结构 + 11 张 Mermaid 图
    firmware/docs/performance_stm32f411.md 431 行 SWD 性能基准
    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
2026-10-14 docs: 第三方探针 SWD 吞吐实测（5 块），并修正 pyocd 写计时被污染的 bug
    新增 firmware/tools/probe_swd_sweep.py
    - 对第三方 CMSIS-DAP 探针做「频率 × 块大小 × 重复次数」的读写吞吐扫描，
    pyocd 与 OpenOCD 两个工具都支持，输出 CSV + 屏幕汇总表。
    - 两个工具都支持在**同一条会话里改频率**（pyocd 用 probe.set_clock()，OpenOCD 用
    adapter speed），整轮扫描只连接一次，避免把反复连接的固定开销算进结果。
    - 测试方法与本工程原有一致：测试区 0x20000000、先整块备份测完逐字还原、
    填充模式 0xA5A50000|i、每组合预热后测 N 次取中位数、每轮读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
2026-10-25 feat(ch32x035): 双串口 + DTR/RTS、SWD 引脚层重构、UART RX DMA 与 WCH-Link 可选编译
    主要功能
    - 串口：COM1 = USART4(PB0/PB1)，COM2 = USART2(PA2/PA3)。单串口 + 流控模式下
    PA2/PA3 作为 DTR/RTS（低有效）输出且不枚举第二个 COM 口；双击 PB3 切到
    双串口模式（USB 重新枚举、PB12 指示、模式存用户选择字 Data1）
    - 调试器模式改为「上电按住 PB3」切换（CMSIS-DAP <-> WCH-Link），取消运行期
    按键切换，避免误触导致重新枚举
    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
2026-10-26 feat: Enhance SWD pin mapping and SPI support
    - Updated SWD pin mapping in swd_pin_map.h to include new variant PA5/PA7 for improved hardware SPI support.
    - Added configuration options in xmake.lua for selecting SWD pin variants and enabling hardware SPI for SWD write data phase.
    - Introduced flash_speed.ps1 and flash_speed_test.tcl scripts for measuring flash programming speed on STM32F4, including erase, program, and verify timing.
    - Implemented swd_link_check.ps1 to assess the health of the SWD link, providing feedback on link quality based on examination success rates.
    - Modified openocd_speed_test.tcl to optimize read operations using dump_image instead of read_memory for better perform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
2026-10-26 Remove hardware SPI support for SWD data phases
    - Deleted the implementation of hardware SPI for SWD data phases in swd_spi_x035.c, including all related functions and comments.
    - Updated swd_pin_map.h to remove configurations related to SPI data phases and their dependencies.
    - Modified xmake.lua to eliminate options for enabling hardware SPI and its clock prescaler, ensuring that all SWD operations revert to GPIO bit-banging.
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2026-10-27 Update uDap project files: change isolated pin label warning to error, add nRST label, and revise README with updated performance data
2026-10-28 fix: update DAP_config.h path in scripts and add uDap configuration tool
    - Updated comments in `openocd_speed_sweep.ps1` and `speed.ps1` to reflect the correct path for `DAP_config.h`.
    - Added a new Python script `udap_config.py` for managing uDap vendor commands, including functionalities for UART mode, LED mode, debugger mode, and entering bootloader.
    - Enhanced README to include new features such as UF2 bootloader and vendor command capabilities.
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
